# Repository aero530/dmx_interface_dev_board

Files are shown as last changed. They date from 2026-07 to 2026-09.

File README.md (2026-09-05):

# DMX Interface Dev Board v2 — Altium hardware

Production hardware for the **DMX Interface Rev 2**: a W6300-EVB-Pico2 (RP2350 +
W6300) carrier that takes Art-Net / sACN / wired DMX / USB in and drives eight
WS2812 strings, split across **two boards**. This repository holds the Altium
sources and generated manufacturing outputs. The firmware, design record, review
history and bring-up checklist live in `dmx_interface_firmware`.

| Board | Project | Size / stack | Job |
|---|---|---|---|
| **DMX Interface DB v2** (logic board) | `DMX Board/DMX Interface DB v2.PrjPcb` | 110 × 81.5 mm, 4-layer JLC04162H-7628, 1 oz outer / 0.5 oz inner, controlled impedance (USB 90 Ω, DMX 120 Ω) | Module, isolated DMX, FTDI USB-DMX port, UI, power tree, 8 × PTC-fused aux/data outputs |
| **LED Power Board** | `LED Power Board/LED Power Board.PrjPcb` | 85 × 90 mm, 4-layer, **2 oz outer** / 0.5 oz inner | Strip power only: screw-terminal input, 8 × 5 A MINI blade fuses, 470 µF per output, pluggable 5.08 mm outputs |

## Folder map

```
DMX Board/
  DMX Interface DB v2.PrjPcb      Altium project (7 sheets, harness-connected)
  Block Diagram.SchDoc            top sheet: module ↔ UI/LED/FTDI/DMX/Power, PSU options noted
  RP2350.SchDoc                   W6300-EVB-Pico2 socket (U1), RUN header, pin map
  WS2812.SchDoc                   SN74ACT245 level shift, 330 R series, 8 × PTSM 3-pin outputs with 3 A PTCs
  DMX.SchDoc                      isolated RS-485 front end (THVD1400, TLP2368 ×3, 1S7BE DC-DC), XLR-5 in/out
  FTDI.SchDoc                     FT232RNL self-powered USB-DMX port, USB-C, USBLC6, RESET# gate
  Power.SchDoc                    V_LED input (J26), F9 → L2/U6 → 5V_LOGIC → D2 → V_SYS → TLV75733, USB power paths
  UI.SchDoc                       TCA9555 (0x20), PCA9633 (0x62), M24C02 (0x56), TFT/button/PWM headers
  *.Harness                       harness definitions for the block diagram
  DMX Interface.PcbDoc            layout
  DMX Interface_Assy.PCBDwf, _FAB.PCBDwf   assembly / fabrication drawings
  DMX Interface.BomDoc            ActiveBOM (variant "Production")
  Job1.OutJob                     output job → "Project Outputs for DMX Interface DB v2/"
  Project Outputs for DMX Interface DB v2/
    BOM/  Gerber NC Drill/  OrCadPCB2Netlist/  PCB Print/  PCBDrawing/
    Report Board Stack/  Schematic Print/  Status Report.Txt
  review.md, DMX_Interface_Rev1_Design_Review.md   the Rev 1 (Nucleo + RP2040) review — identical copies, historical

LED Power Board/
  LED Power Board.PrjPcb, Sheet1.SchDoc, PCB1.PcbDoc
  Assembly Drawing.PCBDwf, Fabrication Drawing.PCBDwf, ActiveBOM.BomDoc
  Job1.OutJob (plus Assembly*.OutJob / Fabrication.OutJob)
  Project Outputs/                same structure as above

DMX_Interface_Multiboard_Project/   Altium multi-board project tying the two boards together (Assembly1.MbaDoc)
Panel Templates/                    only ECO logs — ignored
```

`.gitignore` excludes `__Previews/`, `History/` and every `Project Logs*/`
folder. The `Project Outputs` folders **are** tracked: they are what gets sent
to the fab and what the reviews were run against.

## Electrical summary

**Sources for `V_LED` on the logic board** (three, any one boots the logic):

1. **J26** (Molex Micro-Fit+ 206832-0801, 4 × V_LED + 4 × GND) from the PSU /
   LED Power Board — full power. Strip current stays on the power board; the
   logic board carries only its logic branch and eight 3 A aux/data feeds.
2. **FTDI USB-C (J2) with a plain 5 V brick** — low-power installs. U14
   TPS2553DBVR-1 USB power switch: current limit ≈ 1.45 A (R37 18k),
   reverse-voltage cut-off, EN from TCA9555 **P04** (R38 pull-down, off until
   firmware drives it high), FAULT to **P07** (R35 pull-up), soft start, then F2
   0ZCF0200FF2C 2 A PTC. **5 V build only** — F2 is DNP on 12/24 V builds.
3. **Module USB** — bench feed only: D3 B360A → F18 0.5 A PTC → V_LED.

The brick also boots the logic directly on any build through F1 (1.1 A PTC)
→ D4 → 5V_LOGIC. VBUS present-detect dividers (10k/20k) go to TCA9555 P05
(FTDI) and P06 (module). Trim the PSU to ≥ 5.2 V so it wins when both are
attached.

**Logic branch:** V_LED → F9 1.1 A PTC → L2 ferrite (5 V build) *or* U6
OKI-78SR-5/1.5 (12/24 V builds) → 5V_LOGIC (C17 47 µF SP-Cap) → D2 B340A →
V_SYS → module buck and U9 TLV75733 (3V3, enabled by module 3V3_OUT through
JP3/R26/R31 so the carrier rail never rises before the RP2350 IOVDD). L3 →
5V_LVL_SHIFT for U10.

**Build variants (one voltage per board, silk-marked):**

| | 5 V | 12 V | 24 V |
|---|---|---|---|
| L2 ferrite / U6 OKI | L2 fitted, U6 DNP | U6 fitted, L2 DNP | U6 fitted, L2 DNP |
| D1 TVS | SMDJ5.0A | SMDJ12A | SMDJ26A |
| F2 (brick path) | fitted | DNP | DNP |
| F10–F17 output PTCs | 0ZCF0300BF2C | 0ZCF0300BF2C | 0ZCF0150FF2C (≥ 30 V) |
| C2 | 50 V part on all builds | | |

**LED Power Board:** J3 (OSTYK, both positions V_LED) and J6 (both GND) →
eight Keystone 3544-2 MINI holders with 5 A 0297005.WXNV fuses → 470 µF per
output → Würth 691319510004 headers, mating plugs 691351500002. R1 10k bleed.
There is **no fuse, TVS or reverse protection on this board**: a 40–50 A
MIDI/ANL fuse in the PSU harness is required, and the only clamp is D1 on the
logic board through the J26 cable. Rated 8 × 5 A = 40 A through the board;
input band ≈ 15 mm of 2 oz copper, each output ≈ 8.5 mm.

**Isolation:** the DMX side (THVD1400, XLR shells excepted) sits on 3V3ISO /
GNDISO from PS1 (GAPTEC 1S7BE, 1 kV); plane split on both inner layers,
optocouplers straddle the gap; XLR shells bond to CHGND via PTH3 / R4 (0 Ω
fitted) / C1 (DNP).

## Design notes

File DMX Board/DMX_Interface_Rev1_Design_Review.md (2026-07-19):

# DMX Interface Rev 1 — Full Design Review

**Scope:** All 22 schematic sheets plus embedded netlist and BOM from `DMX_Interface_DB.pdf` (carrier board with NUCLEO-H563ZI + RP2040 Pico, isolated DMX front end, drive-select matrix, and SmartLED / Low-Power / High-Power output modules). Connectivity claims below were traced through the netlist embedded in the PDF, not just the drawings. Where the PDF extraction was ambiguous, the item is explicitly marked **VERIFY**.

**Verdict:** The architecture is sound and most of the board checks out — connector pin maps between carrier and modules are consistent, the isolation barrier is crossed correctly, I²C pull-up topology is clean, and the keying scheme prevents most mis-mating. However, this review found **several new hard errors on the RP2040 pin assignment and the drive-select matrix** that were not in your existing notes, plus two **absolute-maximum-rating hazards** (TLC59116 at 24 V, and 5 V into RP2040 GPIOs via the SmartLED level shifter). Details and a prioritized Rev 2 change list follow.

---

## 1. Critical — will not work as drawn

### 1.1 RP2040 DMX_I2C pins cannot map to a hardware I²C controller ⚠️ NEW

Netlist (sheet 10): `DMX_I2C.ALERT#` = GP4 (pin 6), `DMX_I2C.SDA` = **GP5** (pin 7), `DMX_I2C.SCL` = **GP6** (pin 9), annotated "I2C1".

On the RP2040, SDA is only available on even-numbered GPIOs and SCL on odd-numbered ones:

| GPIO | I²C capability |
|---|---|
| GP4 | I2C0 **SDA** |
| GP5 | I2C0 **SCL** |
| GP6 | I2C1 **SDA** |
| GP7 | I2C1 **SCL** |

As wired, SDA sits on an SCL-only pin and SCL on an SDA-only pin, and even relabeling in firmware leaves them on *different* controllers (GP5→I2C0, GP6→I2C1). **No hardware I²C configuration exists for this net assignment.** Since DMX_I2C is the STM32↔RP2040 inter-processor link and the RP2040 will most likely be the slave/peer, falling back to PIO I²C slave is possible but painful.

**Fix (Rev 2):** move `DMX_I2C.SDA` → GP6 and `DMX_I2C.SCL` → GP7 (valid I2C1 pair), and relocate `DMX_SPI.CS1` off GP7 (see 1.2 — GP9 is free and solves both problems). Alternatively SDA=GP4 / SCL=GP5 (I2C0) with ALERT# moved to GP6.

### 1.2 DMX_SPI.CS1 on GP7 is not a hardware SPI chip-select ⚠️ NEW

The populated solder-bridge configuration (SB2, SB5 ON; SB4, SB6 DNP) routes `DMX_SPI.MOSI` → GP8 (**SPI1 RX**) and `DMX_SPI.MISO` → GP11 (**SPI1 TX**), i.e. the RP2040 is wired as the **SPI slave** with the STM32 (SPI6) as master. GP10 = SPI1 SCK is correct. But `DMX_SPI.CS1` lands on **GP7**, which is SPI0 TX — not a CSn pin. The PL022 in slave mode requires CS on a hardware CSn pin (SPI1 CSn = GP9 or GP13). GP13 is taken by `RP2040_SCL`; **GP9 (module pin 12) is currently unconnected** and is the natural fix.

Until fixed, hardware SPI slave mode cannot frame transactions; you'd need a PIO SPI slave.

### 1.3 Drive-select matrix crosses RP_LED3.Data and RP_LED4.Data ⚠️ NEW

On the Drive Select sheet, the RP2040-side (pin 3) nets of the LED data jumpers are crossed relative to the clock jumpers:

| Jumper | Module net (pin 2) | STM32 side (pin 1) | RP2040 side (pin 3) |
|---|---|---|---|
| JP17 | LED3_CLK | STM32_LED3.Clock | RP_LED3.Clock ✓ |
| JP18 | LED3_DAT | STM32_LED3.Data | **RP_LED4.Data ✗** |
| JP19 | LED4_CLK | STM32_LED4.Clock | RP_LED4.Clock ✓ |
| JP20 | LED4_DAT | STM32_LED4.Data | **RP_LED3.Data ✗** |

JP12/13/15/16 (channels 1–2) are consistent. With the RP2040 selected as LED driver, channel 3's clock pairs with channel 4's data and vice versa. The RP2040 can absorb this in firmware (PIO pin mapping is free), but it will silently corrupt any code that assumes the net names — and the same crossover is reflected on the block-diagram sheet, so it propagates into documentation. Swap the pin-3 nets of JP18/JP20.

Note also: with the default build, the RP2040 cannot drive channel 4 at all — `RP_LED4.Clock`/`RP_LED4.Data` reach GP10/GP11 only through **DNP** bridges SB8/SB3, which are shared with the DMX_SPI pins. That's a deliberate either/or, but worth stating in the docs.

### 1.4 SmartLED DIR net anomalies — **VERIFY in Altium** ⚠️ NEW

The extracted netlist shows the SN74ACT245 `DIR` node (U10 pin 1, JP21 pin 2) also containing **J18 pin 3 and J20 pin 3**, and possibly **U13 pin 1 (EEPROM E0) plus JP24 pin 2**. Two problems if real:

1. J10/J13 carry V_LED on pins 1 *and* 3, but J18/J20 carry V_LED only on pin 1 — pin 3 lands on the DIR logic node. A strip plugged into J18/J20 expecting power on pin 3 would fight or glitch the transceiver direction. There's no evident reason for power connectors to carry DIR.
2. If E0/JP24 truly share the node: JP21 selects 5V_LVL_SHIFT/GND and JP24 selects 3V3/GND on the *same net*. Both at default (1-2) would short **5 V to GND**, and any high state puts 5 V on the M24C02's E0 pin (abs max VCC + 1 V = 4.3 V). The EEPROM address table ("default 0x56", E0=0) also stops being independently settable.

PDF net extraction can merge adjacent nets, so treat this as a must-verify rather than a confirmed fault — but the J18/J20 pin-3 assignment is suspicious even in the most charitable reading.

### 1.5 3V3 → RP_VSYS ideal diode (U14) non-functional — known

Confirmed: AP74700 requires ~4 V minimum anode voltage, so the 3V3 ORing leg into RP_VSYS is dead, as your sheet-1 note says. TPS2116 / LM66100 / Schottky-OR are the right class of fix. (RP_VSYS is happy from 1.8 V, so even a Schottky's drop from 3.3 V is fine.)

---

## 2. Damage and ratings risks

### 2.1 TLC59116 outputs are 17 V absolute max — 24 V supplies will kill the LP module ⚠️ NEW

The carrier explicitly supports 24 V Meanwell bricks (sheet 1 lists LSP-160-24T / UHP-200-24), and V_LED is bussed unchanged to the Low-Power module's J37 common-anode connectors. The TLC59116's OUTx pins are rated **17 V absolute maximum** in the off state; the sheet note itself says "(12V 3W)". Nothing electrically or mechanically prevents installing the LP module with a 24 V supply — the off-state sink pins will see 24 V and exceed abs max. At minimum, silkscreen + docs must restrict the LP module to ≤12 V (≤15 V with margin); a better Rev 2 fix is a module-local regulator/clamp or a keying/interlock convention per supply voltage.

### 2.2 Reverse direction on U10 drives 5 V into non-5V-tolerant RP2040 pins ⚠️ NEW

The SN74ACT245 runs at `5V_LVL_SHIFT`. JP21 in the DIR-low position (B→A, "read data back from strips") turns the A-side pins into ~5 V CMOS outputs driving straight through the module connector and drive-select into the MCU pins with no series resistance. STM32H5 FT pins tolerate this; **RP2040 GPIOs do not (max VDDIO + 0.3 V ≈ 3.6 V)**. If the reverse direction is ever a supported mode, add series resistors and/or clamp, or drop U10's VCC to 3.3 V for that use case. If it's not a supported mode, remove the JP21 GND option or document it as forbidden. Also note DIR is common to all 8 bits, and a direction flip while the MCU still drives its outputs creates transceiver-vs-MCU contention.

### 2.3 TVS and reverse-polarity protection on V_LED — known, plus one addition

SMAJ26A (D1/D2/D7) at 26 V standoff over a 24 V rail leaves ~2 V margin; supply turn-on overshoot can bias the TVS into leakage/heating. SMAJ28A/30A recommended. Additional point: the TVS conducts hard on reverse polarity but there is **no fuse or series element on any V_LED input** (J8/J30/J32) — a reversed 200 W brick will destroy the TVS and then the board. A polyfuse or input FET per module power connector is cheap insurance even on a dev board.

### 2.4 TLC59116 Rext floor — known, confirmed

R57 = 120 Ω fixed + VR1 (3306P, spec'd 30 Ω–1 kΩ but wiper can approach 0 Ω). At wiper ≈ 0, Rext → 120 Ω → ~156 mA/channel, above the 120 mA device limit. Raise R57 to ≥160 Ω so the minimum is safe regardless of trimmer position.

### 2.5 TLC59116 thermal budget — worth a calculation ⚠️ NEW

As a linear sink, per-channel dissipation is (V_LED − V_string) × I_OUT. At 12 V with short strings and ~117 mA, several channels active can put multiple watts into one TSSOP28. Run the worst-case sum for your intended loads; you may want to mandate series resistors or higher-Vf strings to move dissipation off-chip.

### 2.6 Jumper/e-fuse configuration hazards ⚠️ NEW

- **JP14 in the 5 V position with a 12/24 V supply** puts V_LED directly into U9 (LS0504, 6 V abs max) and onto `5V_LVL_SHIFT` → U10 and the strips. One wrong solder bridge = dead module. Consider an auto-select (comparator or wide-Vin buck) instead of a bridge, or at least prominent silkscreen.
- F1/F2 PTCs are 6 V parts. They never see >5 V while the AP74700s block correctly, but a shorted Q1/Q2 exposes them to 24 V, beyond their interrupt rating. Acceptable dev-board risk; noting for awareness.
- JP1/JP22/JP23 populated *with* an external brick present is actually safe (the ideal diodes block reverse into USB) — the silkscreen warnings are belt-and-braces, which is fine.

### 2.7 Multiple modules, multiple power inputs ⚠️ NEW

Each module carries its own brick input (J8, J30, J32) and all common onto the same V_LED through the carrier. Plugging *different* bricks into two installed modules (e.g., 5 V and 24 V) back-drives one supply from the other. Document "one brick per system," or add ORing/blocking per module input in a future rev.

---

## 3. Functional and performance findings

### 3.1 RP2040 DMX UART pins require PIO ⚠️ NEW (likely intentional — confirm)

`DMX.RX` = GP0, `DMX.EN` = GP2, `DMX.TX` = GP3. GP0 is UART0 **TX**-capable (not RX), and GP3 is UART0 CTS (not TX) — so the hardware UART cannot service DMX on these pins in either direction. Since DMX break/MAB timing is normally done with PIO on the RP2040 anyway (e.g., pico-dmx), this is fine *if intended* — but if you ever wanted the hardware UART as a fallback, RX belongs on GP1/GP13/GP17 and TX on GP0/GP4/GP8/GP12/GP16. Worth a schematic note either way.

### 3.2 Opto LED drive margin (RX path) — known, quantified

U8 input: (3.3 V − ~1.4 V Vf − VOL) / 470 Ω ≈ **3.8 mA**. Check this against the TLP2368 threshold input current across temperature; the recommended operating IF for these photo-IC couplers is typically ≥6.5 mA. Dropping R13 to ~270 Ω would put you comfortably in the recommended range (THVD1400 RO can sink it).

### 3.3 R-78K3.3-1.0 minimum input — known

With a 5 V brick, V_LED minus L2 DCR and ripple sits right at the R-78K3.3's ~4.75 V minimum. Fine at 12/24 V. If 5 V operation matters, consider a lower-Vin-min module or LDO bypass path.

### 3.4 STM32 hardware PWM availability for the HP module — refined ⚠️ NEW DETAIL

HP module PWM sources (via J17_H): PWM1 = LED1_DAT or LED1_CLK (JP26, default CLK), PWM2 = LED2_DAT, PWM3 = LED3_DAT, PWM4 = LED4_DAT. Mapping to STM32 pins:

| Signal | STM32 pin | SPI AF | Timer channel |
|---|---|---|---|
| LED1_CLK | PA5 | SPI1_SCK | **TIM2_CH1 ✓** (JP26 default — good) |
| LED1_DAT | PD7 | SPI1_MOSI | none (verify) |
| LED2_DAT | PC3 | SPI2_MOSI | none (verify) |
| LED3_DAT | PB2 | SPI3_MOSI | none (verify) |
| LED4_DAT | PE14 | SPI4_MOSI | **TIM1_CH4 ✓** |
| LED2_CLK | PB10 | SPI2_SCK | TIM2_CH3 ✓ |
| LED4_CLK | PE12 | SPI4_SCK | TIM1_CH3N ✓ |

So on the STM32, only PWM1 (via JP26→CLK) and PWM4 get hardware PWM; PWM2/PWM3 fall back to software toggling. If HP dimming from the STM32 matters, add JP26-style CLK/DAT select jumpers to PWM2 and PWM4 as well (LED2_CLK = PB10/TIM2_CH3 and LED4_CLK = PE12/TIM1_CH3N are usable), and verify the "none" entries against the H563 datasheet AF table. RP2040 side is a non-issue (PWM/PIO on any pin).

### 3.5 Series resistors on DAT only

R17–R20 (330 Ω, provisional) are in the data lines only; clocks go straight from U10 to the LED connectors. For APA102-class strips on any cable length, matching series R on CLK helps edges/ringing just as much. Add provisional footprints on the four CLK lines.

### 3.6 Dual 3V3 sources / Nucleo contention — known, with one addition

The carrier 3V3 (U11) ties to the Nucleo's 3V3 pin **through the unannotated `R?` 0 Ω** (see §6) — so the contention point is at least depopulatable. Document the required Nucleo solder-bridge configuration for external-3V3 powering, and give R? a real designator so it shows up in assembly docs.

### 3.7 No fusing on LED power outputs ⚠️ NEW

J10/J13/J18/J20, LED1–4, J37_PWMx, and J33 all distribute up to a 200 W brick with no per-output protection. A shorted strip cable turns the wiring into the fuse. Recommend polyfuses or fuse footprints per output group in Rev 2.

### 3.8 Module EEPROM addressing — known

U13/U15/U21 all default to 0x56 (E1/E2 strapped high via 0 Ω, E0 low). Fine with one module per connector position, but strapping each module *type* to a distinct 0x5x enables type detection by address probe. TLC59116 at 0x60 (+ all-call/sub-call/SWRST in the 0x68–0x70 region) doesn't collide with 0x56 — bus is clean.

---

## 4. Connector and pinout verification

Traced pin-for-pin through the netlist:

| Interface | Result |
|---|---|
| J7 (carrier, power) ↔ J9_S/L/H (modules) | ✓ Match: 1,2 = V_LED; 3,4 = GND; 5,6 = 3V3; 7,8 = GND |
| J11 (carrier, control) ↔ J12_S/L/H | ✓ Match: 1=ALERT#, 2=SCL, 3=RESET#, 4=SDA, 5=CS1, 6=SCK, 7=CS2, 8=MISO, 9=CS3, 10=MOSI |
| J16 (carrier, LED) ↔ J17_S/L/H | ✓ Match: odd pins = DATn, even pins = CLKn, n = 1..4 |
| HP PWM mapping | ✓ Consistent: J17_H pins 3/5/7 (= LED2/3/4_DAT) → PWM2/3/4; no odd/even swap found (resolves the earlier suspicion) |
| Micro-Fit+ keying (A-key LED1–4 vs D-key J10/13/18/20) | ✓ Prevents signal/power mis-mating |
| DMX XLR genders | ✓ J5 male = input, J15 female = output — matches DMX512 convention |
| SmartLED channel numbering | Confirmed mechanism of your silkscreen note: U10 A1/A2 carry **LED4**_DAT/CLK → B1/B2 → connector "LED1", etc. Pairing (DAT+CLK) is preserved per connector, so it's purely a labeling reversal — connector LEDn carries channel (5−n). Fix silkscreen or swap A-side order in Rev 2. |
| DMX pass-through | ✓ Pins 2/3 (data) and 4/5 (aux pair) bused straight between J5 and J15; JP28 + R15/R16 = switchable 120 Ω termination |
| J5/J15 rendered with "X" | **VERIFY** — confirm placeholder graphic vs. unintended DNP (carried over from previous notes) |
| Board-to-board mating orientation | **VERIFY mechanically** — dual-row RA female (carrier) to dual-row RA male (module) at facing edges should keep pin 1↔pin 1, but row-mirroring is the classic failure mode for this construction; check in 3D/first article |

---

## 5. Items verified OK

- **Isolation barrier crossing:** U3/U7 (TX/EN) LED-side on logic 3V3, output-side on 3V3ISO; U8 (RX) reversed — all correct. PS1 (1S7BE, 1 W) budget ≈ 50–60 mA worst case on 3V3ISO — ample.
- **RS-485 fail-safe bias:** 680 Ω / 120 Ω / 680 Ω gives ≈ 270 mV differential idle — above the 200 mV threshold, plus THVD1400's internal fail-safe. Good.
- **DE//RE tied and driven together** via U7 — correct for a DMX transmitter/transceiver; no local echo, which is fine.
- **CHGND scheme:** XLR shells → CHGND → R1 (0 Ω) → logic GND; XLR pin 1 → GNDISO. Reasonable; keep R1 as the tuning point.
- **I²C pull-up topology:** exactly one 2.2 kΩ set per physical bus segment on each of DMX_I2C, OUTPUT_I2C (STM32 side) / RP2040 I²C (RP side), DISPLAY_I2C — no double termination through the drive-select. 2.2 k at 3.3 V = 1.5 mA sink, fine for Fm.
- **STM32 I²C assignments spot-checked:** I2C1 = PB8/PB9 (DMX) ✓; I2C2 = PF1/PF0 (display) ✓; I2C4_SDA = PF15 and I2C4_SMBA = PF13 (output bus) ✓ — SCL should therefore be PF14; the PDF extraction was ambiguous on that one pin, quick check recommended.
- **RP2040 OUTPUT-side I²C:** GP12/GP13 = valid I2C0 SDA/SCL ✓ (which is what makes the DMX_I2C error in §1.1 stand out).
- **Drive-select SPI/I²C/CLK jumpers** (JP2–JP17, JP19, JP29–JP34): all pin-1/pin-3 source nets consistent; only JP18/JP20 are crossed.
- **RP2040 reset:** STM32 PG1 + J14 jumper onto RUN (internal pull-up on Pico) ✓. RP2040 SWD not broken out on the carrier, but the Pico's own debug pads remain accessible.
- **EEPROM write protection:** WC pulled high (10 k) on all three modules, ground-bridge to enable writes ✓.
- **TLC59116 address straps:** JP35–38 default to GND → 0x60, matching the note ✓.
- **HP driver (TPS922051) design:** 65 V part, PMEG100T030 (100 V/3 A) catch diode, VIN-referenced LED string with 0.2 Ω sense via 100 Ω/1 nF filter — matches the TI reference topology; component ratings fine at 24 V.
- **Bulk/output caps:** 470 µF/50 V electrolytics, 50 V ceramics on V_LED nodes — rated for the 24 V option ✓ (C12 tantalum is on 3V3ISO at 10 V rating — 3.3/10 derating fine).
- **Q1/Q2/Q3 (55–60 V FETs) and AP74700 (40 V max)** — fine against 24 V exposure.

---

## 6. Documentation / librarian issues

1. `R?` / value `0R?` on sheet 3 — this is the carrier-3V3-to-Nucleo-3V3 tie and it appears as "R?" in the BOM too. Re-run annotation before release.
2. Drive Select sheet has a completely blank title block (no title/number/sheet index).
3. Every sheet says "Sheet x of 22" but the set runs to 24 pages including the layout/BOM pages — reconcile.
4. Silkscreen: LED DAT/CLK flipped; DAT[1-4]/CLK[1-4] should read [4..1] (or fix electrically per §4).
5. Block diagram reflects the JP18/JP20 crossover (§1.3) — fix both together.
6. SmartLED layer to-do noted on the layout page ("add power plane to signal layer").
7. Sheet-1 red note boxes should be resolved/cleared as items close.

---

## 7. BOM review

- **GCM1885C1H101JA16D (C96_HPx, 100 pF) is marked "Not Recommended for New Design"** in your own BOM export — pick a replacement now (e.g., GRM1885C1H101JA01 or GCM equivalent in production status).
- F1 (0ZCG, 3 A) and F2 (0ZCJ, 1 A) are 6 V PTCs — see §2.6.
- VR1 3306P-1-102: single-turn trimmer setting a safety-relevant current limit — a fixed resistor + optional parallel trim, or a multi-turn part, is more robust (pairs with §2.4).
- J11 listed as Würth 613010243121 — confirm this is actually the *socket* variant; that part family number reads like a pin header. All other female/male pairings (Sullins/Adam Tech) look consistent.
- 33 solder-bridge jumpers all default 1-2: confirm that default is correct for **every** instance (it is for the drive-select = STM32 and TLC address = 0x60; verify JP21/JP24/JP26 intents against §1.4 and §3.4).

---

## 8. Prioritized Rev 2 change list

| # | Priority | Change |
|---|---|---|
| 1 | Blocker | Re-pin RP2040 DMX_I2C: SDA→GP6, SCL→GP7 (I2C1) |
| 2 | Blocker | Move DMX_SPI.CS1 GP7→GP9 (SPI1 CSn; GP9 currently free) |
| 3 | Blocker | Swap JP18/JP20 pin-3 nets (RP_LED3.Data ↔ RP_LED4.Data) |
| 4 | Blocker | Resolve SmartLED DIR net: remove J18/J20 pin 3 from DIR; confirm E0/JP24 is a separate net (§1.4) |
| 5 | High | Replace U14 AP74700 with low-voltage ORing (TPS2116/LM66100/Schottky) for 3V3→RP_VSYS |
| 6 | High | Enforce/inhibit LP module above ~15 V V_LED (TLC59116 17 V abs max) |
| 7 | High | Protect RP2040 from 5 V in U10 B→A mode (series R / clamp / forbid mode) |
| 8 | High | Raise R57 so Rext ≥ ~160 Ω at trimmer minimum |
| 9 | Medium | TVS → SMAJ28A/30A; add fusing on V_LED inputs and LED power outputs |
| 10 | Medium | Reduce R13 to ~270 Ω for opto RX margin; verify TLP2368 IF threshold |
| 11 | Medium | Add CLK/DAT select jumpers on HP PWM2/PWM4 for hardware timer channels; verify PD7/PC3/PB2 timer AFs |
| 12 | Medium | Series-R footprints on the four CLK lines to LED connectors |
| 13 | Medium | Distinct EEPROM addresses per module type |
| 14 | Low | Fix silkscreen numbering, annotation (R?), Drive Select title block, sheet counts; replace NRND C96 part; document one-brick rule and Nucleo power-bridge config |

---

*Method note: pin/net claims were cross-checked against the netlist embedded in the PDF (e.g., `PIU507 → DMX_I2C.SDA`, `PIJP1803 → RP_LED4.Data`). RP2040 GPIO function mapping is from the RP2040 datasheet Bank 0 function table. STM32H563 alternate-function claims marked "verify" should be checked against the datasheet AF tables before committing the Rev 2 netlist.*

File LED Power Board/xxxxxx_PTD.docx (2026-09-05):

# xxxxxx_PTD

Programming and Test instructions

# Revision History

Revision | Date | By | Changelog
A | 2024-11-27 | Phil Spindler | Initial Release

# Summary

## Document Parameters

The following parameters are used in other parts of this document and are likely to change over the course of the product life (e.g. when a firmware update is issued).

Parameter | Value
AssyPartNumber | 123456

# Program and Configure

Supporting Information
Purpose | Program board components with necessary firmware for correct device operation, verify firmware.
Prerequisites | Fully assembled circuit card assembly
Equipment | - STLINK v2 - Power source for powering board (5-9V)
Relevant Pinouts | [J3] Programming/Debug Through-Hole Test Points Pin Signal STLINK Pin 1 3.3V 1 2 SWCLK 9 3 SWDIO 7 4 #RESET 15 5 GND 2 6 UART RX - 7 UART TX - 8 #RUN/BOOT - 9 DEBUG MODE - [J4] Power Through-Hole Test Points Pin Signal 1 5-9VDC 2 GND

Process
Note | | n/a
1 | Setup | Connect PCBA to programming and power interface described in “Pinouts” (either via connectors or test pads) using STLINK v2. Note pins in J3 and J4 are through-hole test pads with a pin spacing of 2.54mm and a hole size of 1mm.
2 | Power | Apply power to the device via J4
3 | Program | Program device using the following command. Program_the_thing.exe -i <FIRMWARE FILE PENDING> -s {AssyPartNumber}
4 | Check Result | Programming utility must report success with no errors.

# Verify

Supporting Information
Purpose | Verify board functions correctly
Prerequisites | Fully Assembled, registered, programmed & configured circuit card assembly.
Equipment | - Power source for DUT power (5V -> 9V) - 3.3V UART interface for J3 UART pins
Relevant Pinouts | [J3] Programming/Debug Through-Hole Test Points Pin Signal Host UART Interface 1 3.3V - 2 SWCLK - 3 SWDIO - 4 #RESET - 5 GND GND 6 UART RX RX 7 UART TX TX 8 #RUN/BOOT - 9 DEBUG MODE - [J4] Power Through-Hole Test Points Pin Signal 1 5-9VDC 2 GND
UART Configuration | Baud Rate: 921600 Data Bits: 8 Parity Bits: None Stop Bits: 1

Process
1 | Setup | Connect board to programming and power interface described in “Pinouts” (either via connectors or test pads) using STLINK v2. Note pins in J3 and J4 are through-hole test pads with a pin spacing of 2.54mm and a hole size of 1mm.
2 | Power | Apply power to the device via J4
3 | Verify | On boot, the device will issue information over the UART interface.

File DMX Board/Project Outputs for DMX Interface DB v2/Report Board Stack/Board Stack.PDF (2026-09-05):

# Board Stack Report

Stack Up | Layer Stack
Layer | Board Layer Stack | Name | Material | Thickness | Constant

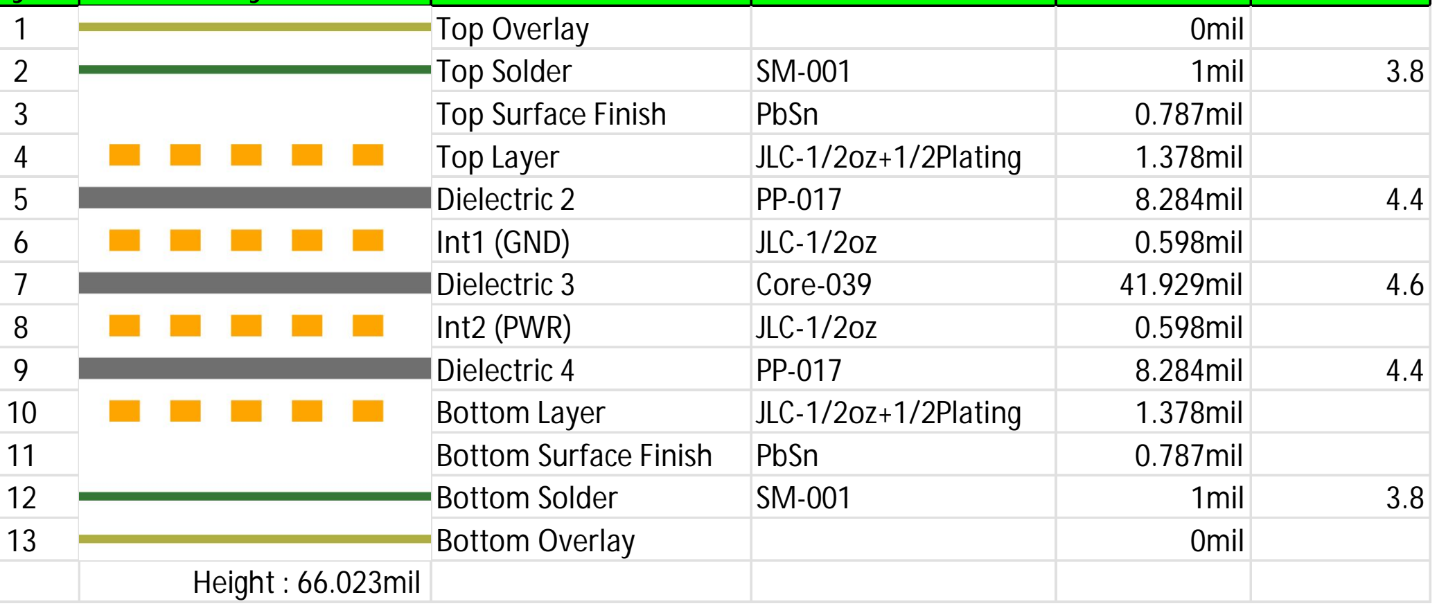
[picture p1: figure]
Top Overlay; 0mil; Top Solder; 1mil; Top Surface Finish; PbSn; 0.787mil; Top Layer; JLC-1/2oz+1/2Plating; 1.378mil; Dielectric 2; 8.284mil; Int1 (GND); JLC-1/2oz; 0.598mil; Dielectric 3; Core-039; 41.929mil; Int2 (PWR); Dielectric 4; Bottom Layer; Bottom Surface Finish; Bottom Solder; Bottom Overlay; Height : 66.023mil

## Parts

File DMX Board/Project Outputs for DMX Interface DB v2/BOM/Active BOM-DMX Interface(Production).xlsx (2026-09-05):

JLCPN | Name | Description | Designator | Footprint | LibRef | Quantity | Manufacturer 1 | Manufacturer Part Number 1 | Supplier 1 | Supplier Part Number 1
C440198 | GRM21BR61H106KE43L | Ceramic Capacitor, Multilayer, Ceramic, 10uF, 50V, 10%, X6S, 0805 | C2 | CAPC2012X14N_0805_MED | CMP-001-00169-2 | 1
 | REH1020471M050K | CAP ALUM 470UF 20% 50V RADIAL TH | C3, C6, C7, C11, C18, C24, C26, C28 | CAP_POL_DIAM10_H22_SPACING5 | CMP-001-00166-2 | 8 | KYOCERA AVX | REH1020471M050K | Mouser | 581-REH1020471M050K
C59782 | C1608X7R1C105K080AC | Ceramic Capacitor, Multilayer, Ceramic, 16V, 10% +Tol, 10% -Tol, X7R, 15% TC, 1uF, Surface Mount, 0603 | C4, C39 | CAPC1608X10N_0603_MED | CMP-001-00121-2 | 2 | TDK | C1608X7R1C105K080AC | Newark | C1608X7R1C105K080AC
C113803 | CC0603KRX7R0BB104 | Ceramic Capacitor, Multilayer, Ceramic, 100V, 10% +Tol, 10% -Tol, X7R, 15% TC, 0.1uF, Surface Mount, 0603 | C5, C8, C9, C10, C13, C14, C16, C23, C29, C30, C32, C33, C34, C36, C42, C43, C44 | CAPC1608X10N_0603_MED | CMP-001-00102-4 | 17 | Yageo Group | CC0603KRX7R0BB104 | Arrow Electronics | CC0603KRX7R0BB104
C55530 | TPSB226K010R0500 | Tantalum Capacitor, Polarized, Tantalum (dry/solid), 10V, 10% +Tol, 10% -Tol, 22uF, Surface Mount, 1210 | C12 | CAPCP3528X21N_1210_1411_MED | CMP-001-00100-5 | 1 | KYOCERA AVX | TPSB226K010R0500 | Arrow Electronics | TPSB226K010R0500
C125847 | CGA4J3X7R1H225K125AE | Ceramic Capacitor, Multilayer, Ceramic, 2.2uF, 50V, 10%, X6S, 0805 | C15, C22 | CAPC2012X14N_0805_MED | CMP-001-00170-2 | 2 | TDK | CGA4J3X7R1H225K125AE | Newark | CGA4J3X7R1H225K125AE
 | EEF-CX1C470R | Polymer Aluminum Electrolytic Capacitor, 47 µF, -55 to 105 ¡C | C17 | FP-SP-Cap-X-MFG | CMP-001-00179-1 | 1
C162413 | GRM21BC81C106KA73L | Ceramic Capacitor, Multilayer, Ceramic, 10uF, 16V, 10%, X6S, 0805 | C31, C40, C41 | CAPC2012X14N_0805_MED | CMP-001-00084-4 | 3 | Murata | GRM21BC81C106KA73L | DigiKey | 490-5519-6-ND
 | GRM21BC81C226ME44L | Ceramic Capacitor, Multilayer, Ceramic, 22uF, 16V, 20%, X6S, 0805 | C38, C45 | CAPC2012X14N_0805_MED | CMP-001-00095-1 | 2
 | SMDJ5.0A | SMDJ Series 6.5 W 7 V Uni-Directional Surface Mount TVS Diode - SMC | D1 | SMDJ_DO-214AB | CMP-004-00055-2 | 1 | Littelfuse | SMDJ5.0A | Arrow Electronics | SMDJ5.0A
 | B340A-13-F | Rectifier Diode, Schottky, 1 Phase, 1 Element, 3A, 40V V(RRM), Silicon | D2 | DO-214AC_SMA | CMP-004-00034-2 | 1 | Diodes Inc. | B340A-13-F | Newark | B340A-13-F
 | B360A-13-F | Rectifier Diode, Schottky, 1 Phase, 1 Element, 3A, 60V V(RRM), Silicon, DO-214AC | D3, D4 | FP-SMA-MFG | CMP-004-00054-1 | 2
 | 1812L110/33MR | PTC Resettable Fuse 1.1A(hold) 1.95A(trip) 33VDC 20A 0.8W 0.5s 0.06Ohm SMD Solder Pad 1812 T/R | F1, F9 | FUSE4532X1.55N_1812MED | CMP-005-00022-1 | 2 | Littelfuse | 1812L110/33MR | Arrow Electronics | 1812L110/33MR
 | 0ZCF0200FF2C | SMD Resettable Fuse, PPTC, 2920 [7351 Metric], 0ZCF, 16 VDC, 2 A, 4 A, 4.5 s | F2 | RESC7451X90M_2920 | CMP-005-00026-1 | 1
 | 0ZCF0300BF2C | Polymeric PTC Resettable Fuse 24V 3 A Ih Surface Mount 2920 (7351 Metric), Conca | F10, F11, F12, F13, F14, F15, F16, F17 | 0ZCF0300BF2C-Footprint-1 | CMP-005-00023-1 | 8
C151162 | 1206L050/15YR | PTC Resettable Fuse 0.5A(hold) 1A(trip) 15VDC 100A 0.6W 0.1s 0.15Ohm SMD Solder Pad 1206 T/R | F18 | FP-1206L-MFG | CMP-005-00020-2 | 1 | Littelfuse | 1206L050/15YR | RS (Formerly Allied Electronics) | 1206L050/15YR
 | 1778638 | Terminal Block, Header, R/A, 3Way, Th; | J1, J3, J13, J16, J20, J21, J24, J25 | 1778638-Footprint-1 | CMP-002-00251-3 | 8
C165948 | TYPE-C-31-M-12 | 20V USB C 2.0 16P Female header | J2 | Type-C-31-M-12 | CMP-002-00236-8 | 1 | Global Connector Technology | USB4105-GF-A | Mouser | 640-USB4105-GF-A
 | Header 8x1 0.1" | Conn Header Vert 8POS 2.54MM | J4 | HEADER 8x1 0.1" | CMP-002-00240-1 | 1 | Adam Tech | PH1-08-UA | Arrow Electronics | PH1-08-UA
 | IO-XLR5-M-BH | B Series, 5 Pin XLR, Male, Horizontal Pcb Mount With Separate Ground Pin | J5 | IO-XLR5-M-BH-Footprint-1 | CMP-002-00191-7 | 1 | Io Audio Technologies | IO-XLR5-M-EH | Jameco (USA) | 2388023
 | Header 5x1 0.1" | Conn Header Vert 5POS 2.54MM | J6, J8 | HEADER 5x1 0.1" | CMP-002-00239-1 | 2 | Adam Tech | PH1-05-UA | Arrow Electronics | PH1-05-UA
 | Header 6x1 0.1" | Conn Header Vert 6POS 2.54MM | J7 | Copy of HEADER 7x1 0.1" | CMP-002-00250-1 | 1
 | Header 2x1 0.1" | Conn Header Vert 2POS 2.54MM | J9, J14 | FP-M20-9990245-MFG | CMP-002-00082-2 | 2 | Adam Tech | PH1-02-UA | RS (Formerly Allied Electronics) | PH1-02-UA
 | 1778845 | Terminal Block Connector; Plug; Mini; Spring Cage; 3; 2.5 mm; 26-20 AWG; 5 A; 150 V | J10, J11, J12, J17, J18, J19, J22, J23 | 1778845-Footprint-1 | CMP-002-00252-2 | 8
 | IO-XLR5-F-BH | B-Series 5-Pin XLR Female Horizontal PCB Mount with Separate Ground-Pin Metal Face Plate | J15 | IO-XLR5-F-BH-Footprint-1 | CMP-002-00192-4 | 1 | Io Audio Technologies | IO-XLR5-F-EH | Mouser | 670-IO-XLR5-F-EH
 | 206832-0801 | Micro-Fit+, Vertical Header, 8 pin | J26 | 206832-0801-Footprint-1 | CMP-002-00208-6 | 1
 | Jumper 3 x 1 Bridge 1-2 Solder Bridge | 0603 Solder Bridge Jumper Surface Mount | JP1, JP2, JP3, JP4, JP5 | Jumper 3 Solder Bridge 1-2 0603 | CMP-009-00341-2 | 5
 | SRR6038-180Y | General Purpose Inductor, 18uH, 30%, 1 Element, Ferrite-Core, SMD, 2727 | L1 | IND_SRR6038-180Y | CMP-006-00028-1 | 1 | Bourns | SRR6038-180Y | Mouser | 652-SRR6038-180Y
 | MPZ2012S601AT000 | Ferrite Beads Multi-Layer Power 600Ohm 25% 100MHz 2A 0.1Ohm DCR 0805 T/R | L2, L3 | FP-MPZ2012-MFG | CMP-006-00035-1 | 2 | TDK | MPZ2012S601AT000 | DigiKey | 445-MPZ2012S601AT000DKR-ND
 | 1S7BE_0303S3U | ISOLATED MODULE DC DC CONVERTERS | PS1 | CONV_1S7BE_0303S3U | CMP-112-000000-3 | 1 | GAPTEC Electronic GmbH & Co. KG | 1S7BE_0303S3U | DigiKey | 3182-1S7BE_0303S3U-ND
 | 2N7002KW | Small Signal Field-Effect Transistor, 0.31A I(D), 60V, 1-Element, N-Channel, Silicon, Metal-oxide Semiconductor FET | Q1 | ONSEMI_SOT65P210X110-3N | CMP-013-00041-2 | 1 | onsemi | 2N7002KW | Arrow Electronics | 2N7002KW
C22962 | RC0603FR-07220RL | Fixed Resistor, Metal Glaze/thick Film, 0.1W, 220ohm, 75V, 1% +/-Tol, 100ppm/Cel, Surface Mount, 0603 | R1, R9, R13 | RESC1608X06N_0603_MED | CMP-009-00202-2 | 3 | Yageo Group | RC0603FR-07220RL | Arrow Electronics | RC0603FR-07220RL
C25803 | RC0603DR-07100KL | Fixed Resistor, Metal Glaze/thick Film, 0.1W, 100000ohm, 75V, 0.5% +/-Tol, 100ppm/Cel, Surface Mount, 0603 | R2, R31, R35, R38 | RESC1608X06N_0603_MED | CMP-009-00328-3 | 4 | Yageo Group | RC0603DR-07100KL | Arrow Electronics | RC0603DR-07100KL
C22935 | RC0603FR-071ML | Fixed Resistor, Metal Glaze/thick Film, 0.1W, 1Mohm, | R3 | RESC1608X06N_0603_MED | CMP-009-00342-2 | 1 | Yageo Group | RC0603FR-071ML | Mouser | 603-RC0603FR-071ML
C21189 | RC0603FR-070RL | RC Series 0603 0.1 W 0 Ohm Jumper Surface Mount Thick Film Chip Resistor | R4, R5, R29, R30, R32, R33, R34 | RESC1608X06N_0603_MED | CMP-009-00204-6 | 7 | Yageo Group | RC0603JR-070RL | Mouser | 603-RC0603JR-070RL
C23138 | RC0603FR-07330RL | Fixed Resistor, Metal Glaze/thick Film, 0.1W, 330ohm, 75V, 1% +/-Tol, 100ppm/Cel, Surface Mount, 0603 | R6, R12, R15, R16, R17, R18, R19, R20, R21 | RESC1608X06N_0603_MED | CMP-009-00302-3 | 9 | Yageo Group | RC0603FR-07330RL | Mouser | 603-RC0603FR-07330RL
C114669 | RC0603FR-07470RL | Fixed Resistor, Metal Glaze/thick Film, 0.1W, 470ohm, 75V, 1% +/-Tol, 100ppm/Cel, Surface Mount, 0603 | R7, R8 | RESC1608X06N_0603_MED | CMP-009-00300-2 | 2 | Yageo Group | RC0603FR-07470RL | Mouser | 603-RC0603FR-07470RL
C112310 | RC0603FR-07680RL | Fixed Resistor, Metal Glaze/thick Film, 0.1W, 680ohm, 75V, 1% +/-Tol, 100ppm/Cel, Surface Mount, 0603 | R10, R11 | RESC1608X06N_0603_MED | CMP-009-00301-2 | 2 | Yageo Group | RC0603FR-07680RL | Arrow Electronics | RC0603FR-07680RL
C114662 | RC0603FR-072K2L | Fixed Resistor, Metal Glaze/thick Film, 0.1W, 2200ohm, 75V, 1% +/-Tol, 100ppm/Cel, Surface Mount, 0603 | R14, R27, R28 | RESC1608X06N_0603_MED | CMP-009-00304-2 | 3 | Yageo Group | RC0603FR-072K2L | Arrow Electronics | RC0603FR-072K2L
C23186 | RC0603FR-075K1L | Fixed Resistor, Metal Glaze/thick Film, 0.1W, 5100ohm, 75V, 1% +/-Tol, 100ppm/Cel, Surface Mount, 0603 | R22, R23 | RESC1608X06N_0603_MED | CMP-009-00331-3 | 2 | Yageo Group | RC0603FR-075K1L | DigiKey | 311-5.10KHRDKR-ND
 | RC0603FR-074K7L | Fixed Resistor, Metal Glaze/thick Film, 0.1W, 4700ohm, 75V, 1% +/-Tol, 100ppm/Cel, Surface Mount, 0603 | R24 | RESC1608X06N_0603_MED | CMP-009-00343-1 | 1 | Yageo Group | RC0603FR-074K7L | DigiKey | 311-4.70KHRDKR-ND
C98220 | RC0603FR-1010KL | Fixed Resistor, Metal Glaze/thick Film, 0.1W, 10000ohm, 75V, 1% +/-Tol, 100ppm/Cel, Surface Mount, 0603 | R25, R26, R39, R41 | RESC1608X06N_0603_MED | CMP-009-00306-2 | 4 | Yageo Group | RC0603FR-1010KL | Arrow Electronics | RC0603FR-1010KL
 | RC1206FR-0710KL | Fixed Resistor, Metal Glaze/thick Film, 0.25W, 20000ohm, 200V, 1% +/-Tol, 100ppm/Cel, Surface Mount, 1206 | R36 | RESC3116X06N_1206MED | CMP-009-00344-1 | 1
 | RC0603FR-0718KL | 100mW Thick Film Resistors 75V ±100ppm/℃ ±1% 18kΩ 0603 Chip Resistor - Surface Mount ROHS | R37 | RESC1608X06N_0603_MED | CMP-009-00346-2 | 1
C123417 | RC0603FR-0720KL | 100mW Thick Film Resistors 75V ±100ppm/℃ ±1% 20kΩ 0603 Chip Resistor - Surface Mount ROHS | R40, R42 | RESC1608X06N_0603_MED | CMP-009-00345-1 | 2
 | W6300-EVB-PICO2 | Raspberry Pi RP2350 and fully hardwired TCP/IP controller W6300 | U1 | W6300-EVB-PICO2_0.4375_standoff | CMP-020-00030-3 | 1 | WIZnet | W6300-EVB-PICO2 | Arrow Electronics | W6300-EVB-PICO2
 | FT232RNL | Integrated Circuit Interface USB-UART; RS-232; 12Mbs; 3.3-5.25V; -40+85 deg.C; SMD; SSOP28 | U2 | FP-FT232RNL-REEL-MFG | CMP-015-00034-4 | 1 | FTDI | FT232RL
 | TLP2368(TPL,E | Logic IC Output Optocoupler, 1-Channel, 1-Element, 3750V Isolation, 20MBps | U3, U7, U8 | SOT125P700X220-5N | CMP-00026-00002-1 | 3 | Toshiba | TLP2368(TPL,E | Arrow Electronics | TLP2368(TPL,E
C3235232 | THVD1400DR | Line Transceiver, 1 Func, 1 Driver, 1 Rcvr, PDSO8 | U4 | SOIC127P600X175-8N | CMP-015-00028-2 | 1 | Texas Instruments | THVD1400DR | Texas Instruments | THVD1400DR
C7519 | USBLC6-2SC6 | Very low capacitance ESD protection | U5 | ESD_SOT23-6L | CMP-128-000006-4 | 1 | STMicroelectronics | USBLC6-2SC6 | Newark | USBLC6-2SC6
 | TLV75733PDYDR | 1-A, low-IQ high-accuracy low-dropout (LDO) voltage regulator with enable 5-SOT-23 -40 to 125 | U9 | SOT95P280X145-5N | CMP-019-00080-1 | 1 | Texas Instruments | TLV75733PDYDR | Texas Instruments | TLV75733PDYDR
C6931 | SN74ACT245PWR | Bus Transceiver, ACT Series, 1-Func, 8-Bit, True Output, CMOS, PDSO20 | U10 | PW0020A_L | CMP-016-00027-3 | 1 | Texas Instruments | SN74ACT245PWR | Arrow Electronics | SN74ACT245PWR
 | PCA9633DP1,118 | PCA9633 Series 25 mA 5.5 V 1 MHz SMT 8-bit I2C-Bus LED Driver - TSSOP-8 | U11 | NXP-TSSOP-8_M | CMP-015-00036-1 | 1 | NXP Semiconductors | PCA9633DP1,118 | Newark | PCA9633DP1,118
 | TCA9555PWR | 16-bit 1.65- to 5.5-V I2C/SMBus I/O expander with interrupt, weak pull-up & config registers | U12 | PW0024A_M | CMP-015-00012-2 | 1 | Texas Instruments | TCA9555PWR | Mouser | 595-TCA9555PWR
C83836 | M24C02-RMN6TP | M24C02 Series 2 Kb (256 x 8) 1.8 V SMT Serial I²C Bus EEPROM - SOIC-8 | U13 | M24C02-RMN6TP-SO8N-IPC_B | CMP-019-00078-2 | 1 | STMicroelectronics | M24C02-RMN6TP | Arrow Electronics | M24C02-RMN6TP
 | TPS2553DBVR-1 | IC PWR SWITCH N-CHAN 1: 1 SOT23-6 Power Switch/Driver 1: 1 N-Channel 1.5A SOT-23-6 | U14 | DBV0006A_N | CMP-019-00083-1 | 1

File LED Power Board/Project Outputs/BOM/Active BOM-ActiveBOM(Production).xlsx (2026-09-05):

JLCPN | Name | Description | Designator | Footprint | LibRef | Quantity | Manufacturer 1 | Manufacturer Part Number 1 | Supplier 1 | Supplier Part Number 1
 | REH1020471M050K | CAP ALUM 470UF 20% 50V RADIAL TH | C1, C2, C3, C4, C5, C6, C7, C8 | CAP_POL_DIAM10_H22_SPACING5 | CMP-001-00166-2 | 8 | KYOCERA AVX | REH1020471M050K | Mouser | 581-REH1020471M050K
 | 5.0SMDJ5.0A | 5V Unidirectional 5kW TVS Diode, 9.2V Vwm, 6.4V Vbr, SMC(DO-214AB), SMD | D1 | SMDJ_DO-214AB | CMP-004-00056-1 | 1
 | 3544-2 | Auto blade fuse holder; for 2.8x0.8mm mini blade fuses ATM; 20A; THT | F1, F2, F5, F6, F10, F11, F15, F16 | 3544-2-Footprint-1 | CMP-005-00025-1 | 8 | Keystone | 3544-2 | Heilind Americas | 3544-2
 | 0297005.WXNV | Fuse Blade 5A 32V Socket 10.9 X 3.8 X 8.8mm Polyamide 66 Automotive UL | F3, F4, F7, F8, F9, F12, F13, F14 | FP-0297-MFG | CMP-005-00024-3 | 8 | Littelfuse | 0297005.WXNV | Arrow Electronics | 0297005.WXNV
 | 691351500002 | Terminal Block, Pluggable, 2Pos, 12Awg; | J1, J2, J4, J5, J7, J8, J9, J10 | 691351500002-Footprint-1 | CMP-002-00248-4 | 8 | Wurth Elektronik | 691351500002 | DigiKey | 732-2040-ND
 | OSTYK51102030 | Conn Terminal Block 2 POS 9.5mm Solder ST Thru-Hole 30A | J3, J6 | OSTYK51102030-Footprint-1 | CMP-002-00246-1 | 2 | On Shore Technology | OSTYK51102030 | DigiKey | ED2953-ND
 | 691319510004 | Terminal Block, 5.08MM, Dbl Lvl Horizontal Male Pcb Header W/closed Flange, 4PI | P1, P2, P3, P4 | 691319510004 | CMP-002-00244-2 | 4 | Wurth Elektronik | 691319510004
 | RC1206FR-0710KL | Fixed Resistor, Metal Glaze/thick Film, 0.25W, 20000ohm, 200V, 1% +/-Tol, 100ppm/Cel, Surface Mount, 1206 | R1 | RESC3116X06N_1206MED | CMP-009-00344-1 | 1 | Yageo Group | RC1206FR-0710KL | Mouser | 603-RC1206FR-0710KL

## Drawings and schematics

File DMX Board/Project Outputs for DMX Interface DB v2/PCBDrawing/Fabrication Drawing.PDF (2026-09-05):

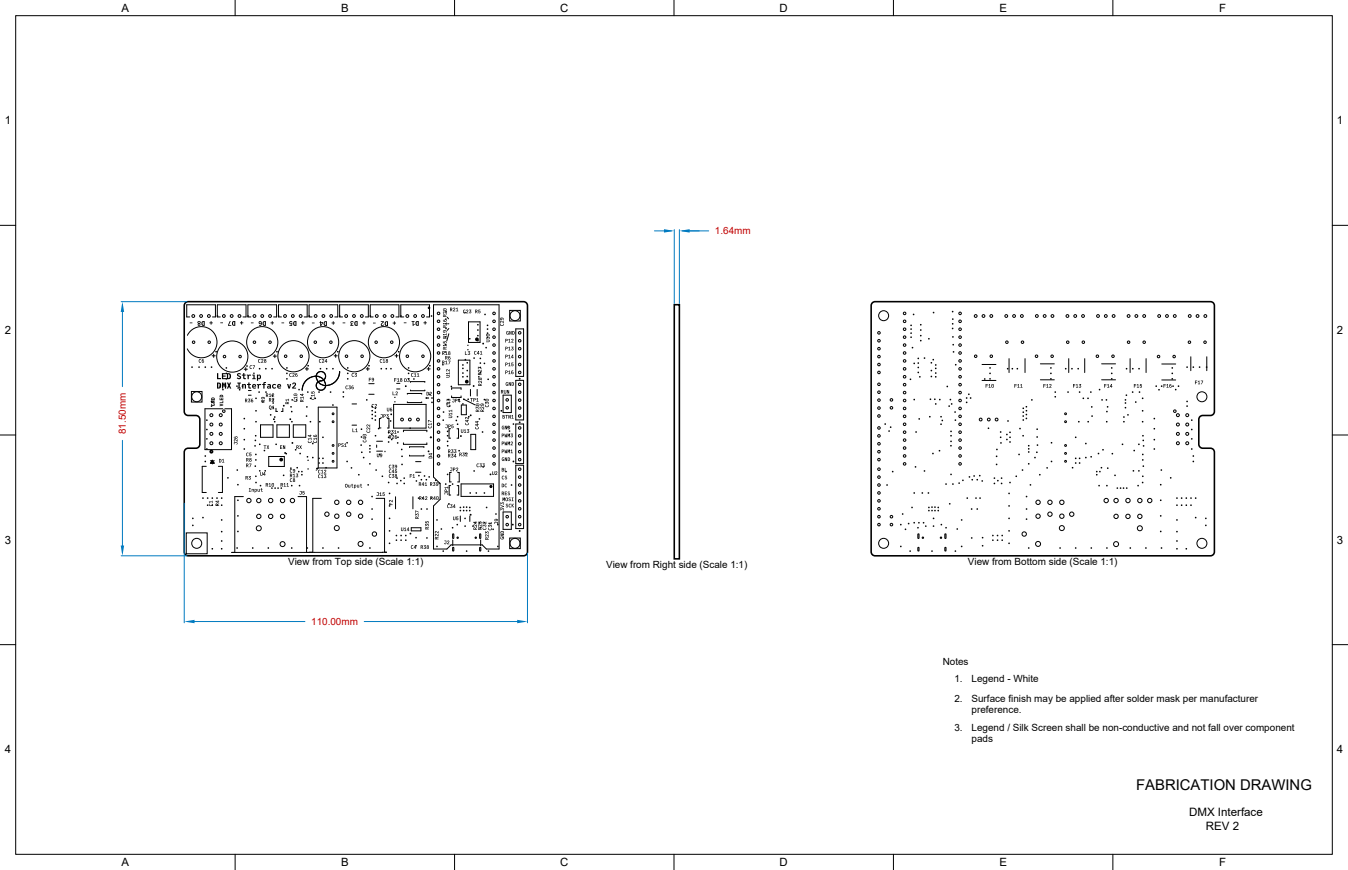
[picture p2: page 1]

Notes
1. Legend - White
Surface finish may be applied after solder mask per manufacturer
preference.
Legend / Silk Screen shall be non-conductive and not fall over component
pads

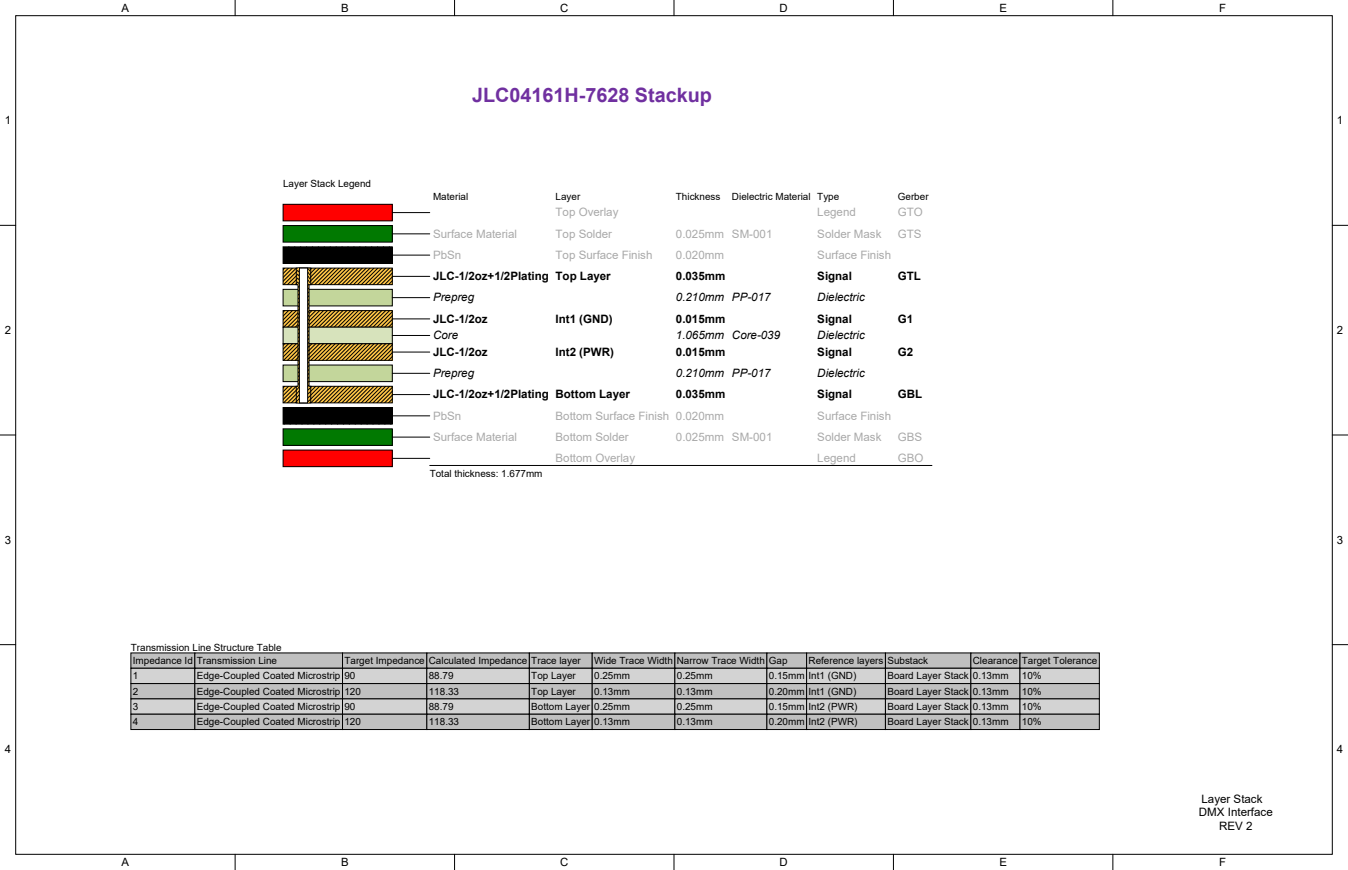
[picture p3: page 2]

Transmission Line Structure Table

Impedance Id | Transmission Line | Target Impedance | Calculated Impedance | Trace layer | Wide Trace Width | Narrow Trace Width | Gap | Reference layers | Substack | Clearance | Target Tolerance
1 | Edge-Coupled Coated Microstrip | 90 | 88.79 | Top Layer | 0.25mm | 0.25mm | 0.15mm | Int1 (GND) | Board Layer Stack | 0.13mm | 10%
2 | Edge-Coupled Coated Microstrip | 120 | 118.33 | Top Layer | 0.13mm | 0.13mm | 0.20mm | Int1 (GND) | Board Layer Stack | 0.13mm | 10%
3 | Edge-Coupled Coated Microstrip | 90 | 88.79 | Bottom Layer | 0.25mm | 0.25mm | 0.15mm | Int2 (PWR) | Board Layer Stack | 0.13mm | 10%
4 | Edge-Coupled Coated Microstrip | 120 | 118.33 | Bottom Layer | 0.13mm | 0.13mm | 0.20mm | Int2 (PWR) | Board Layer Stack | 0.13mm | 10%

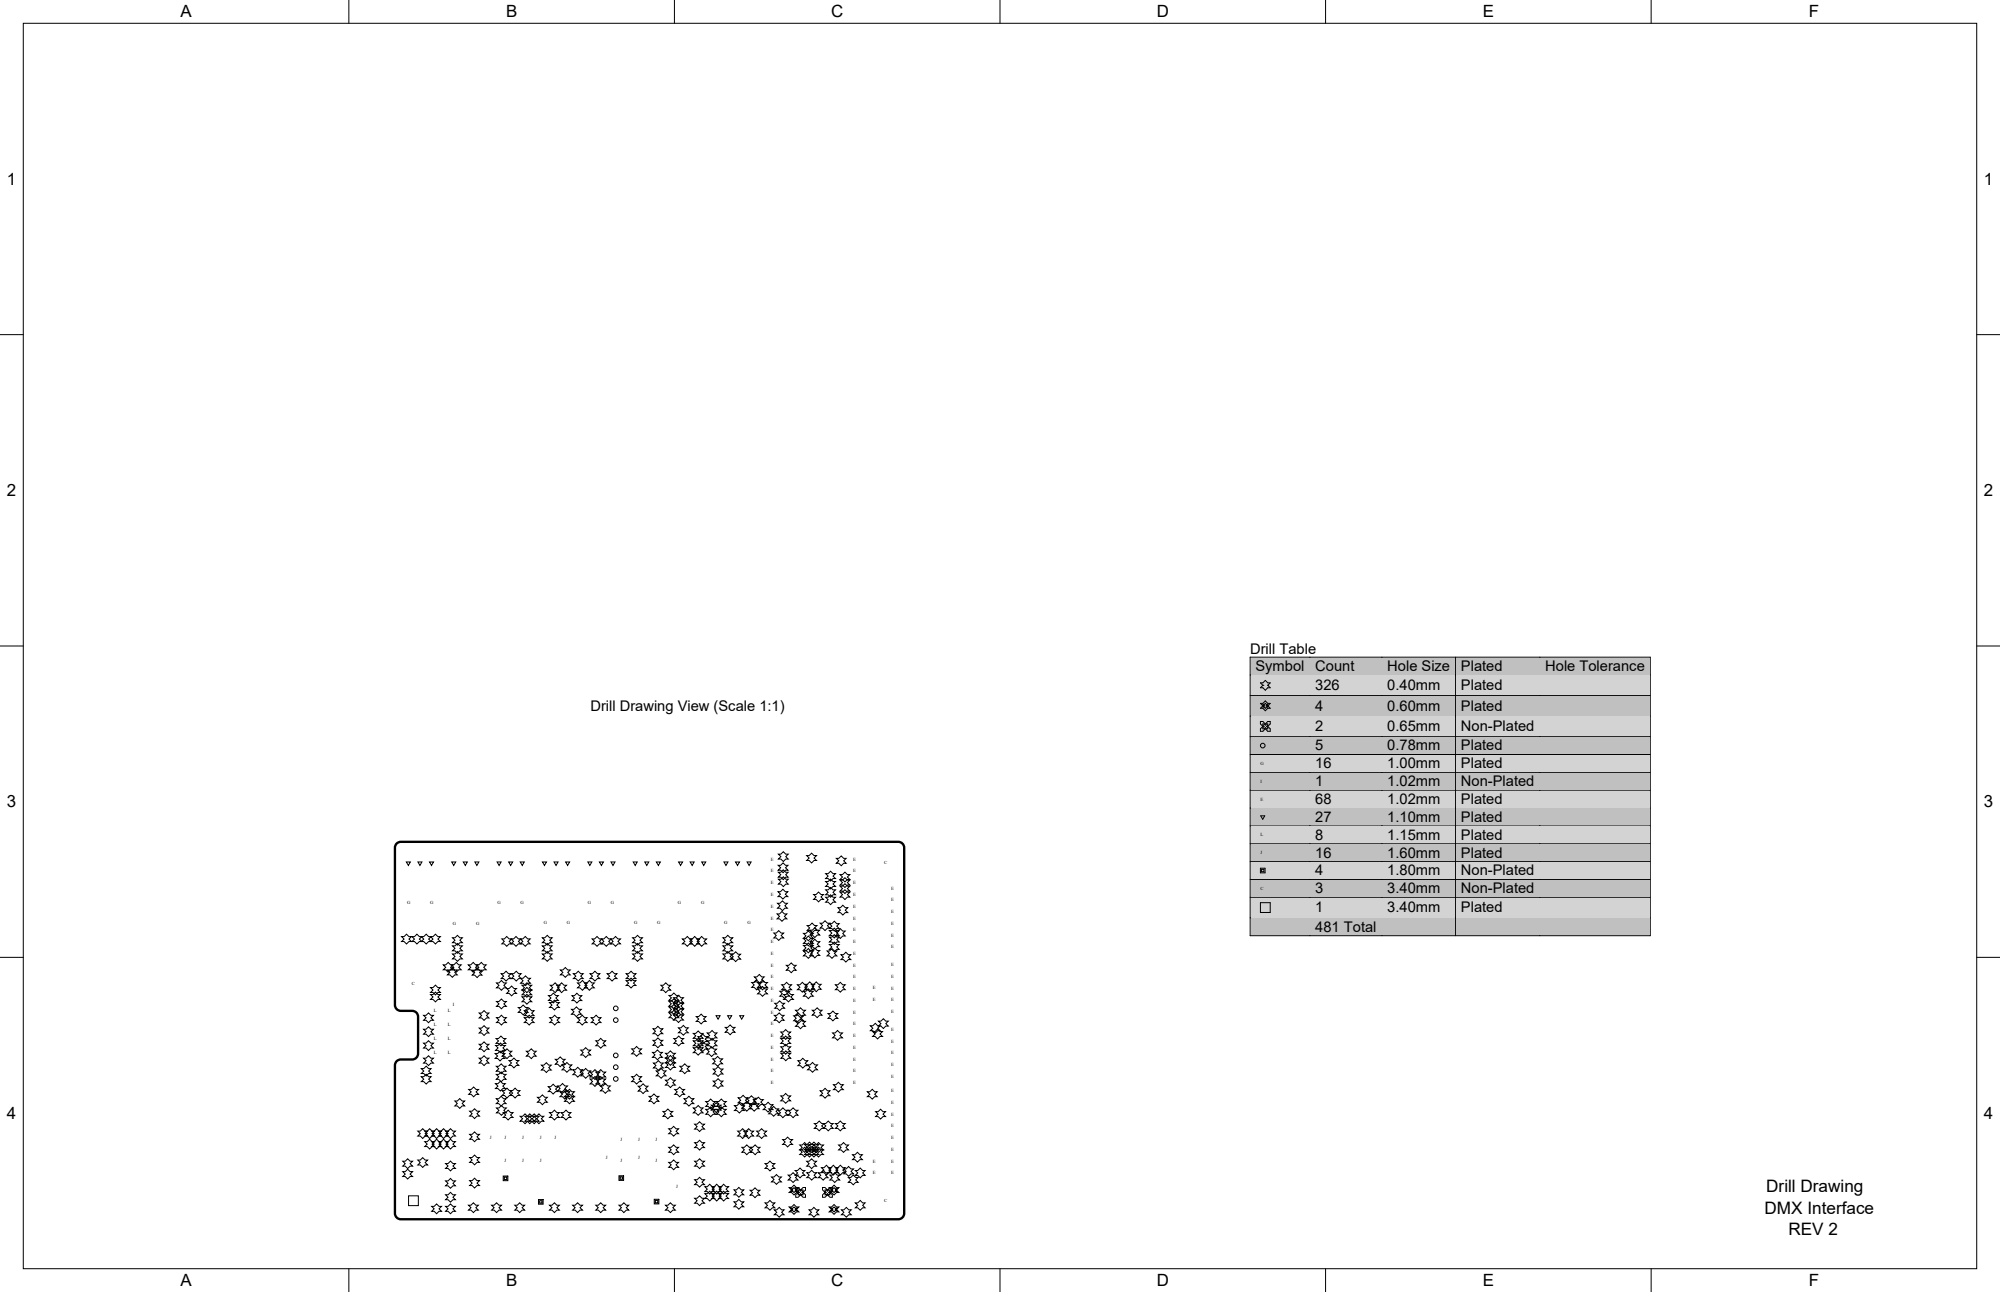
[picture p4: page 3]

Symbol | Count | Hole Size | Plated | Hole Tolerance

326 | 0.40mm | Plated
4 | 0.60mm | Plated
2 | 0.65mm | Non-Plated
5 | 0.78mm | Plated

Drill Drawing View (Scale 1:1)

G | 16 | 1.00mm | Plated

I | 1 | 1.02mm | Non-Plated

E | 68 | 1.02mm | Plated

27 | 1.10mm | Plated

L | 8 | 1.15mm | Plated

J | 16 | 1.60mm | Plated

4 | 1.80mm | Non-Plated

C | 3 | 3.40mm | Non-Plated

1 | 3.40mm | Plated
481 Total

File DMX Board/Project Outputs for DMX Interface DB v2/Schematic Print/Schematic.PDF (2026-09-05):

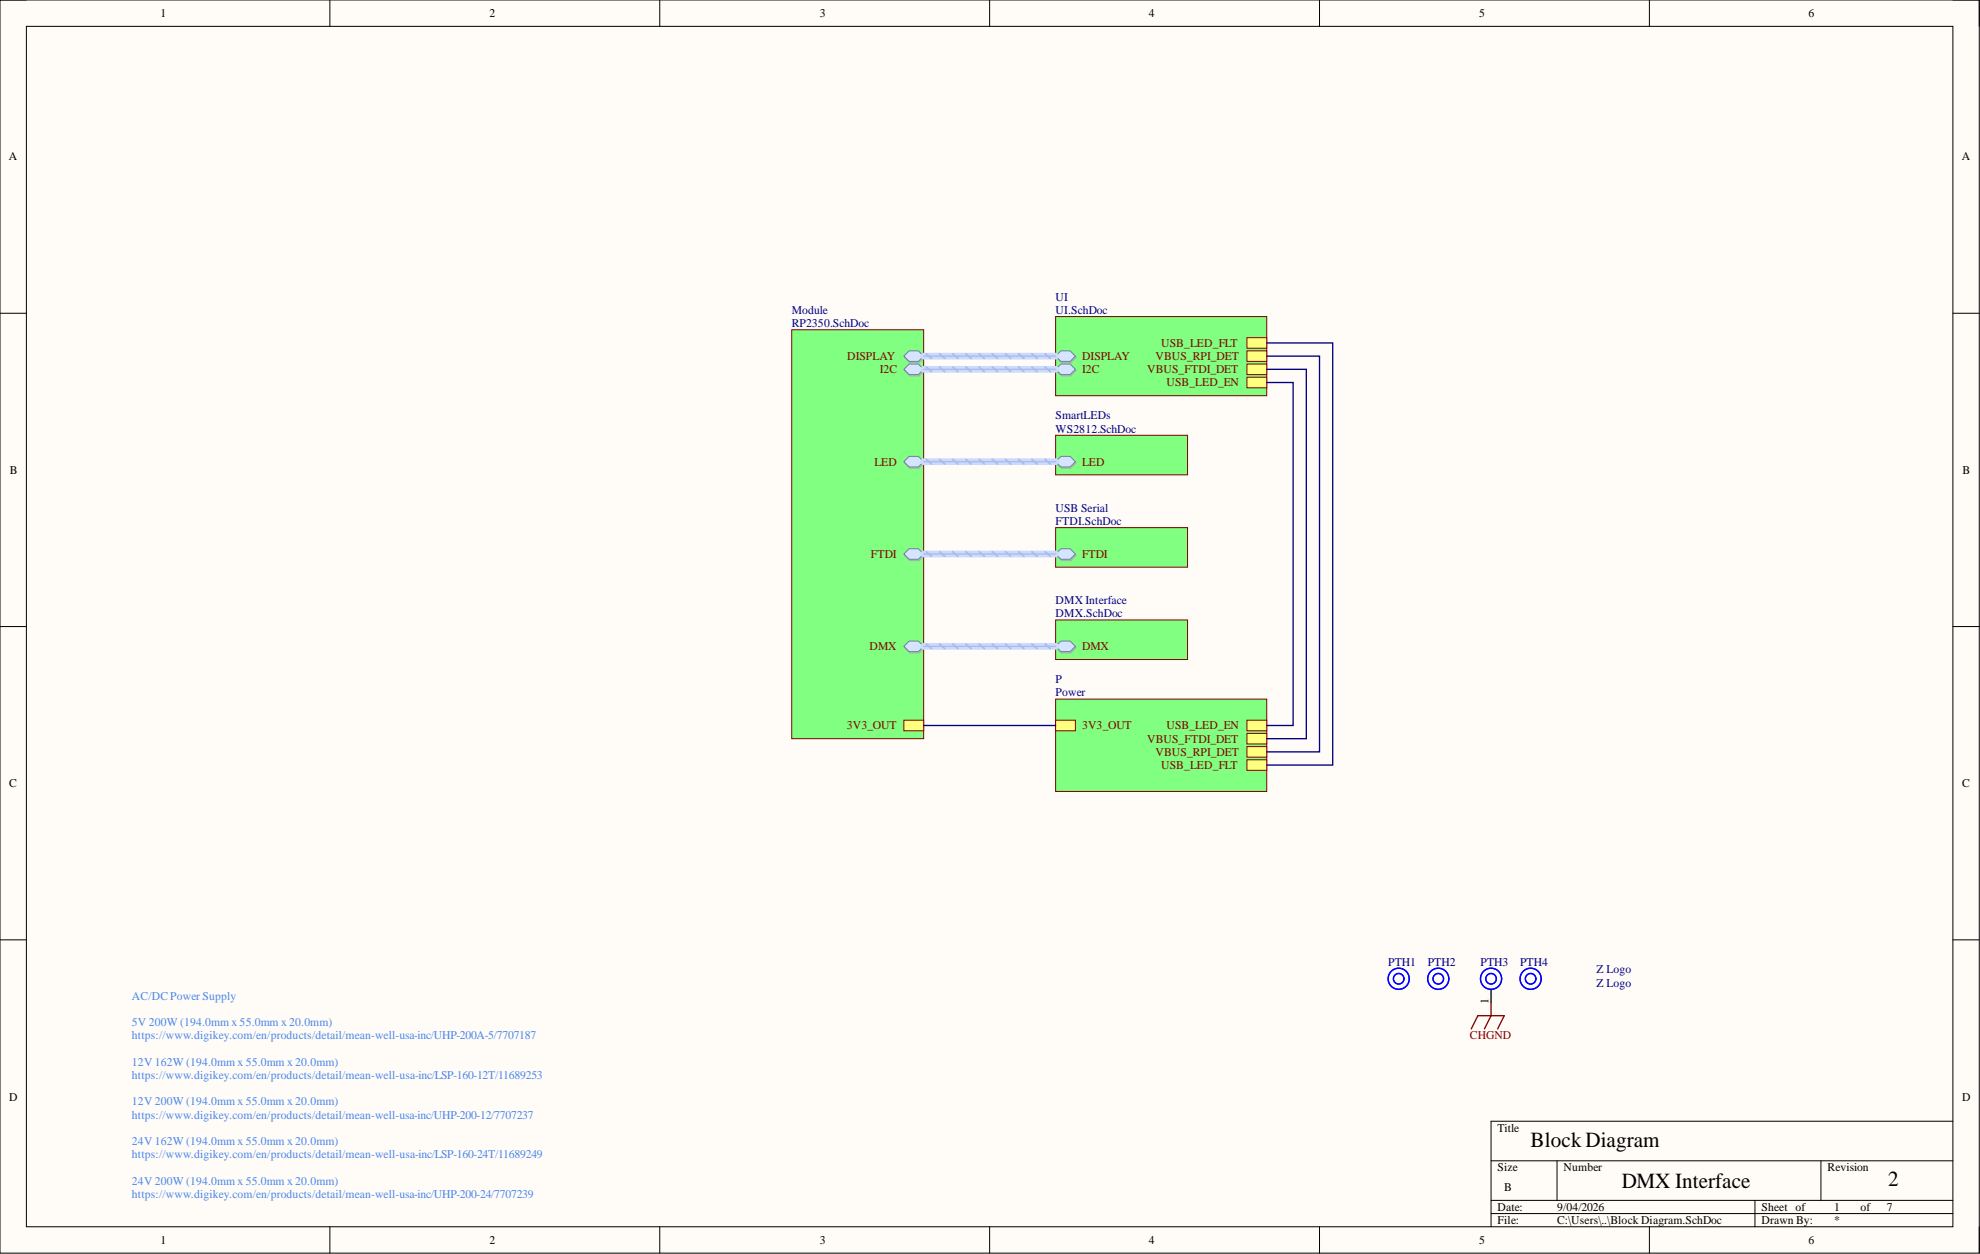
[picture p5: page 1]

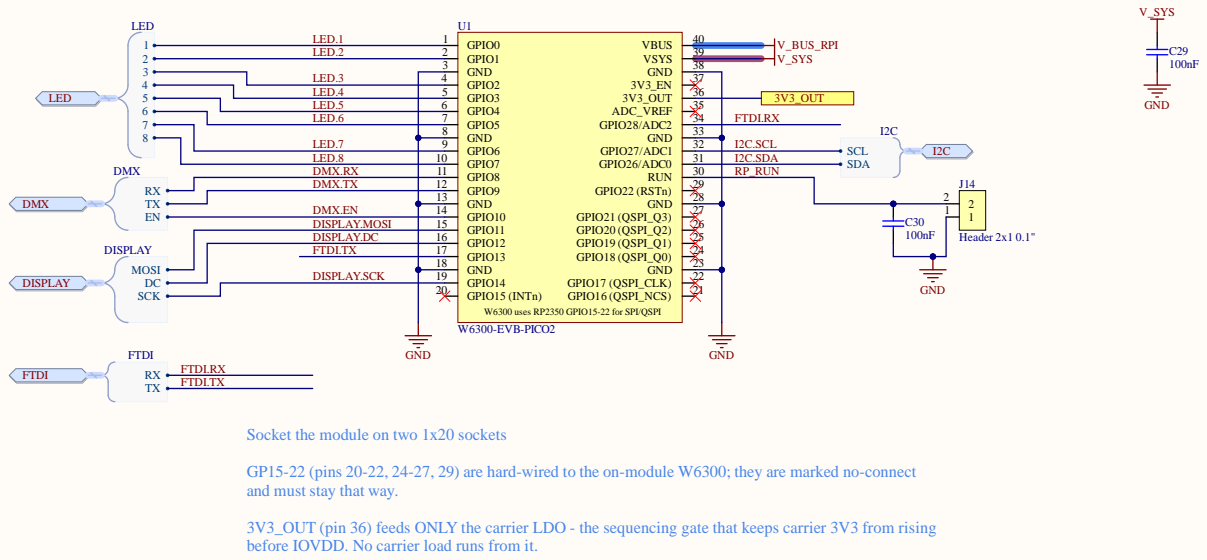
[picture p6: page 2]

L E D . 3 | | 4 | 3 7 6
L E D . 4 | | 5 | 3
L E D . 5 | | 6 | 3 5 4 3
L E D . 6 | | 7 | 3 3

L E D . 7 | | 9 | 3 2 3 1 30 9 RUN
L E D . 8 | 1 | 0

1 4 | | | 2 7 6 5 4 3 | 1
1 5 | | | 2

DISPL AY. D C | 1 | 6 | | 2
FT DI. T X | 1 1 | 7 8 | | 2

DISPL AY.S C K | 1 | 9 | 2 2 1

that keeps carrier 3V3 from rising

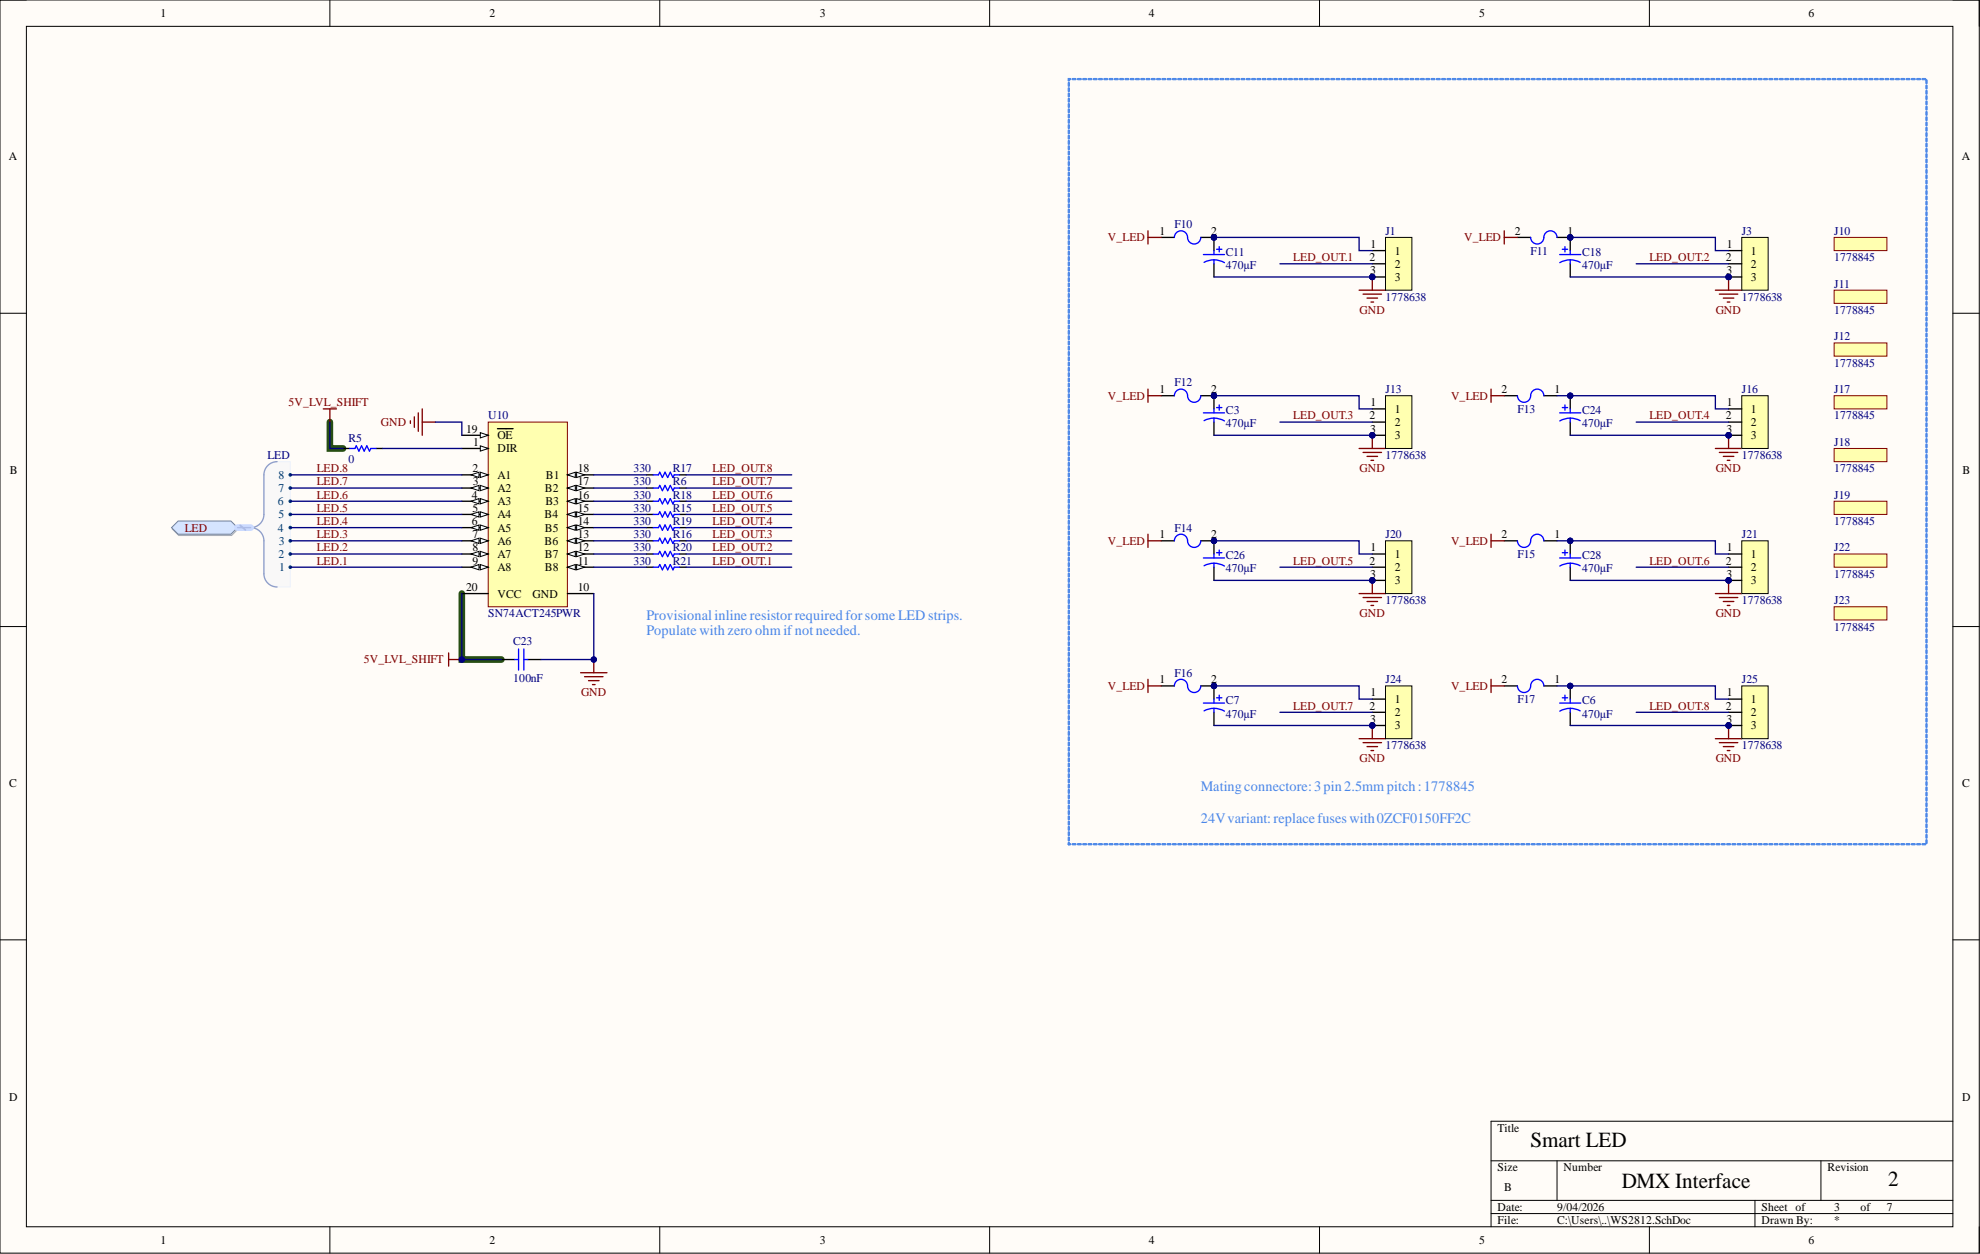
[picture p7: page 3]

d for some LED strips.

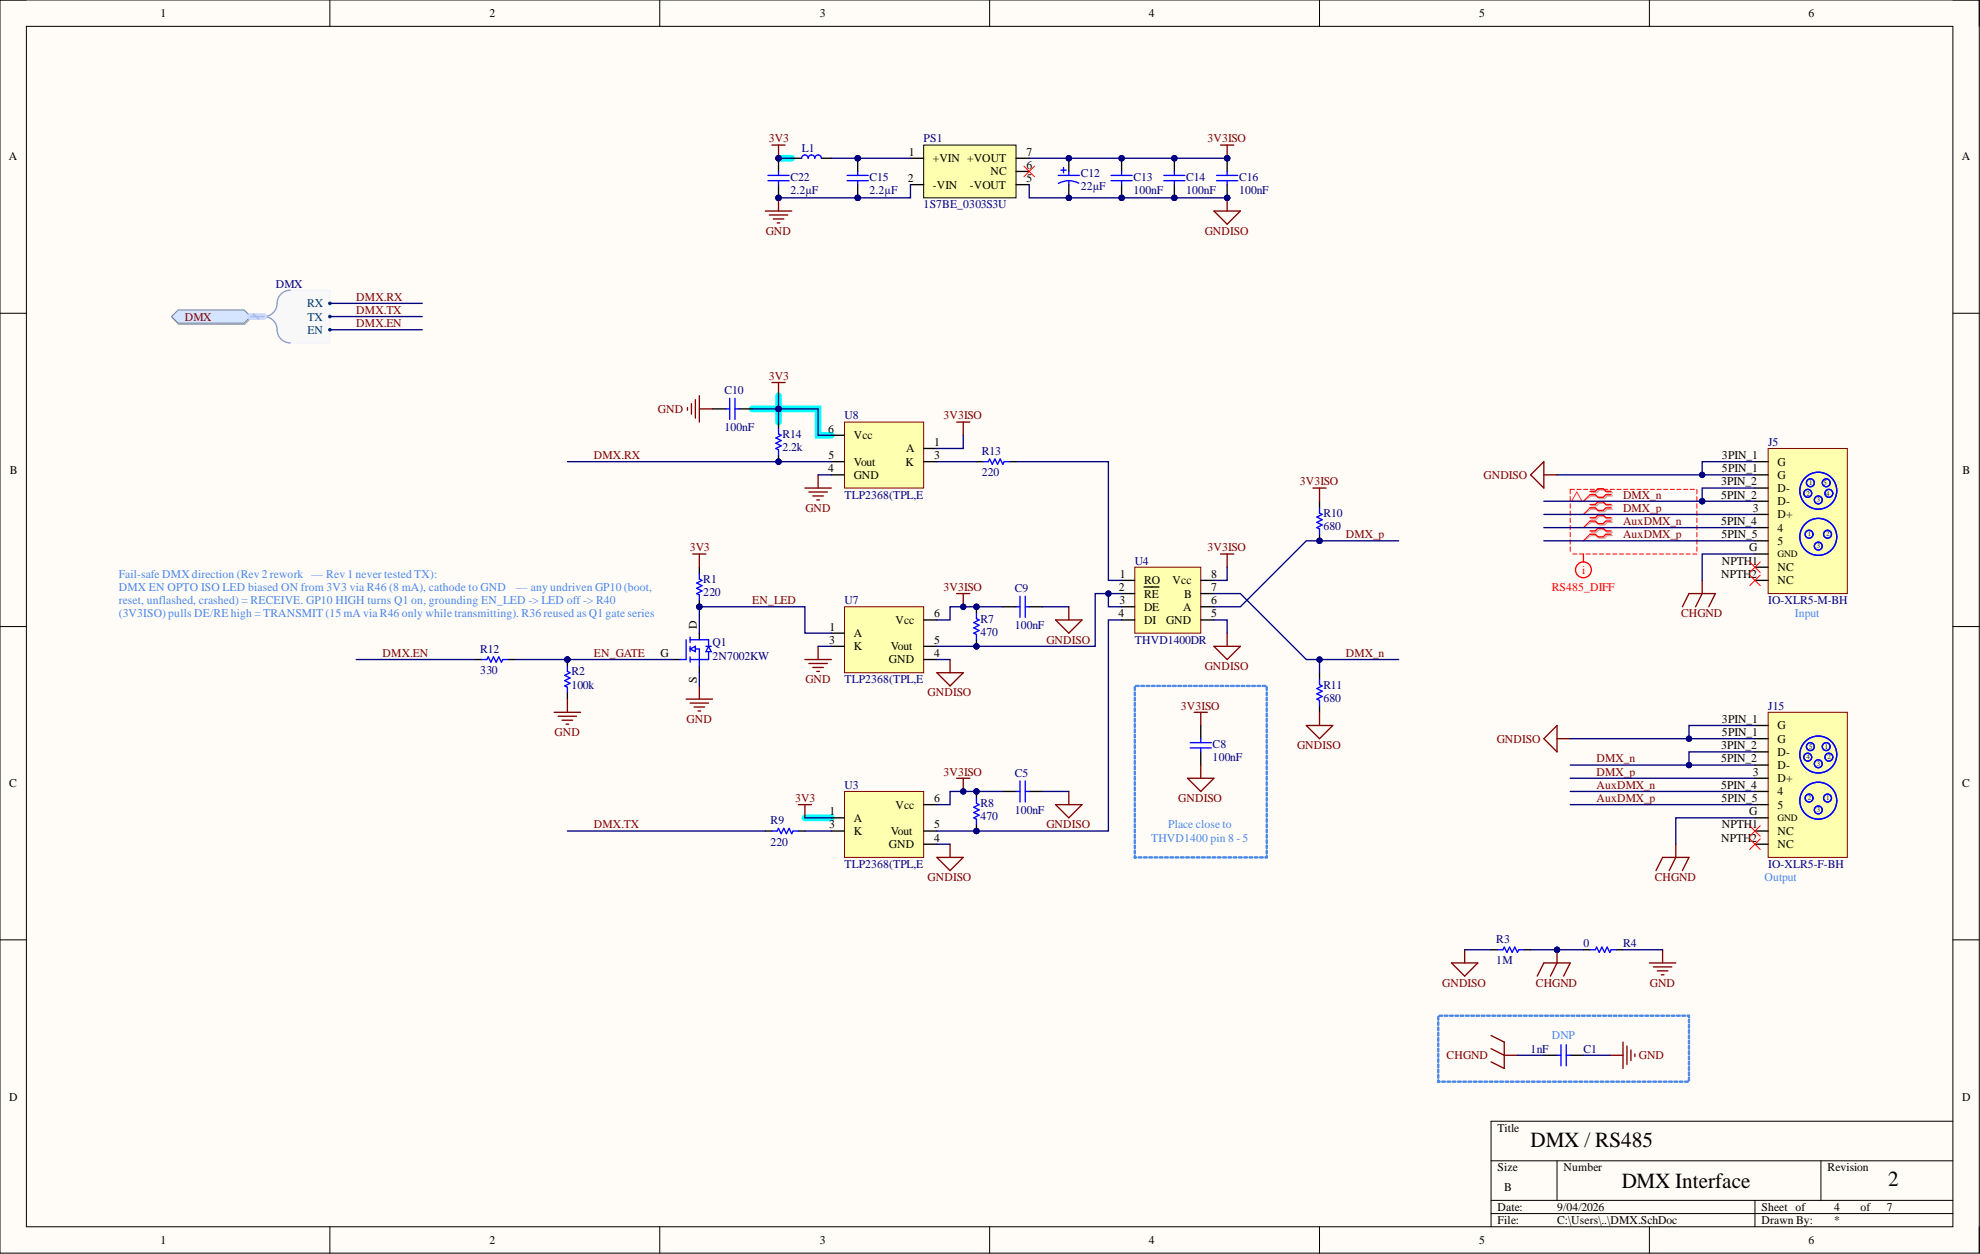
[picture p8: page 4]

DMX_p | D+ 3
AuxDMX_n | 4 5PIN_4
AuxDMX_p | 5 5PIN_5

GND G
NC NPTH1

Fail-safe DMX direction (Rev 2 rework — Rev 1 never tested TX):
DMX EN OPTO ISO LED biased ON from 3V3 via R46 (8 mA), cathode to GND — any undriven GP10 (boot,
reset, unflashed, crashed) = RECEIVE. GP10 HIGH turns Q1 on, grounding EN_LED -> LED off -> R40
(3V3ISO) pulls DE/RE high = TRANSMIT (15 mA via R46 only while transmitting). R36 reused as Q1 gate series

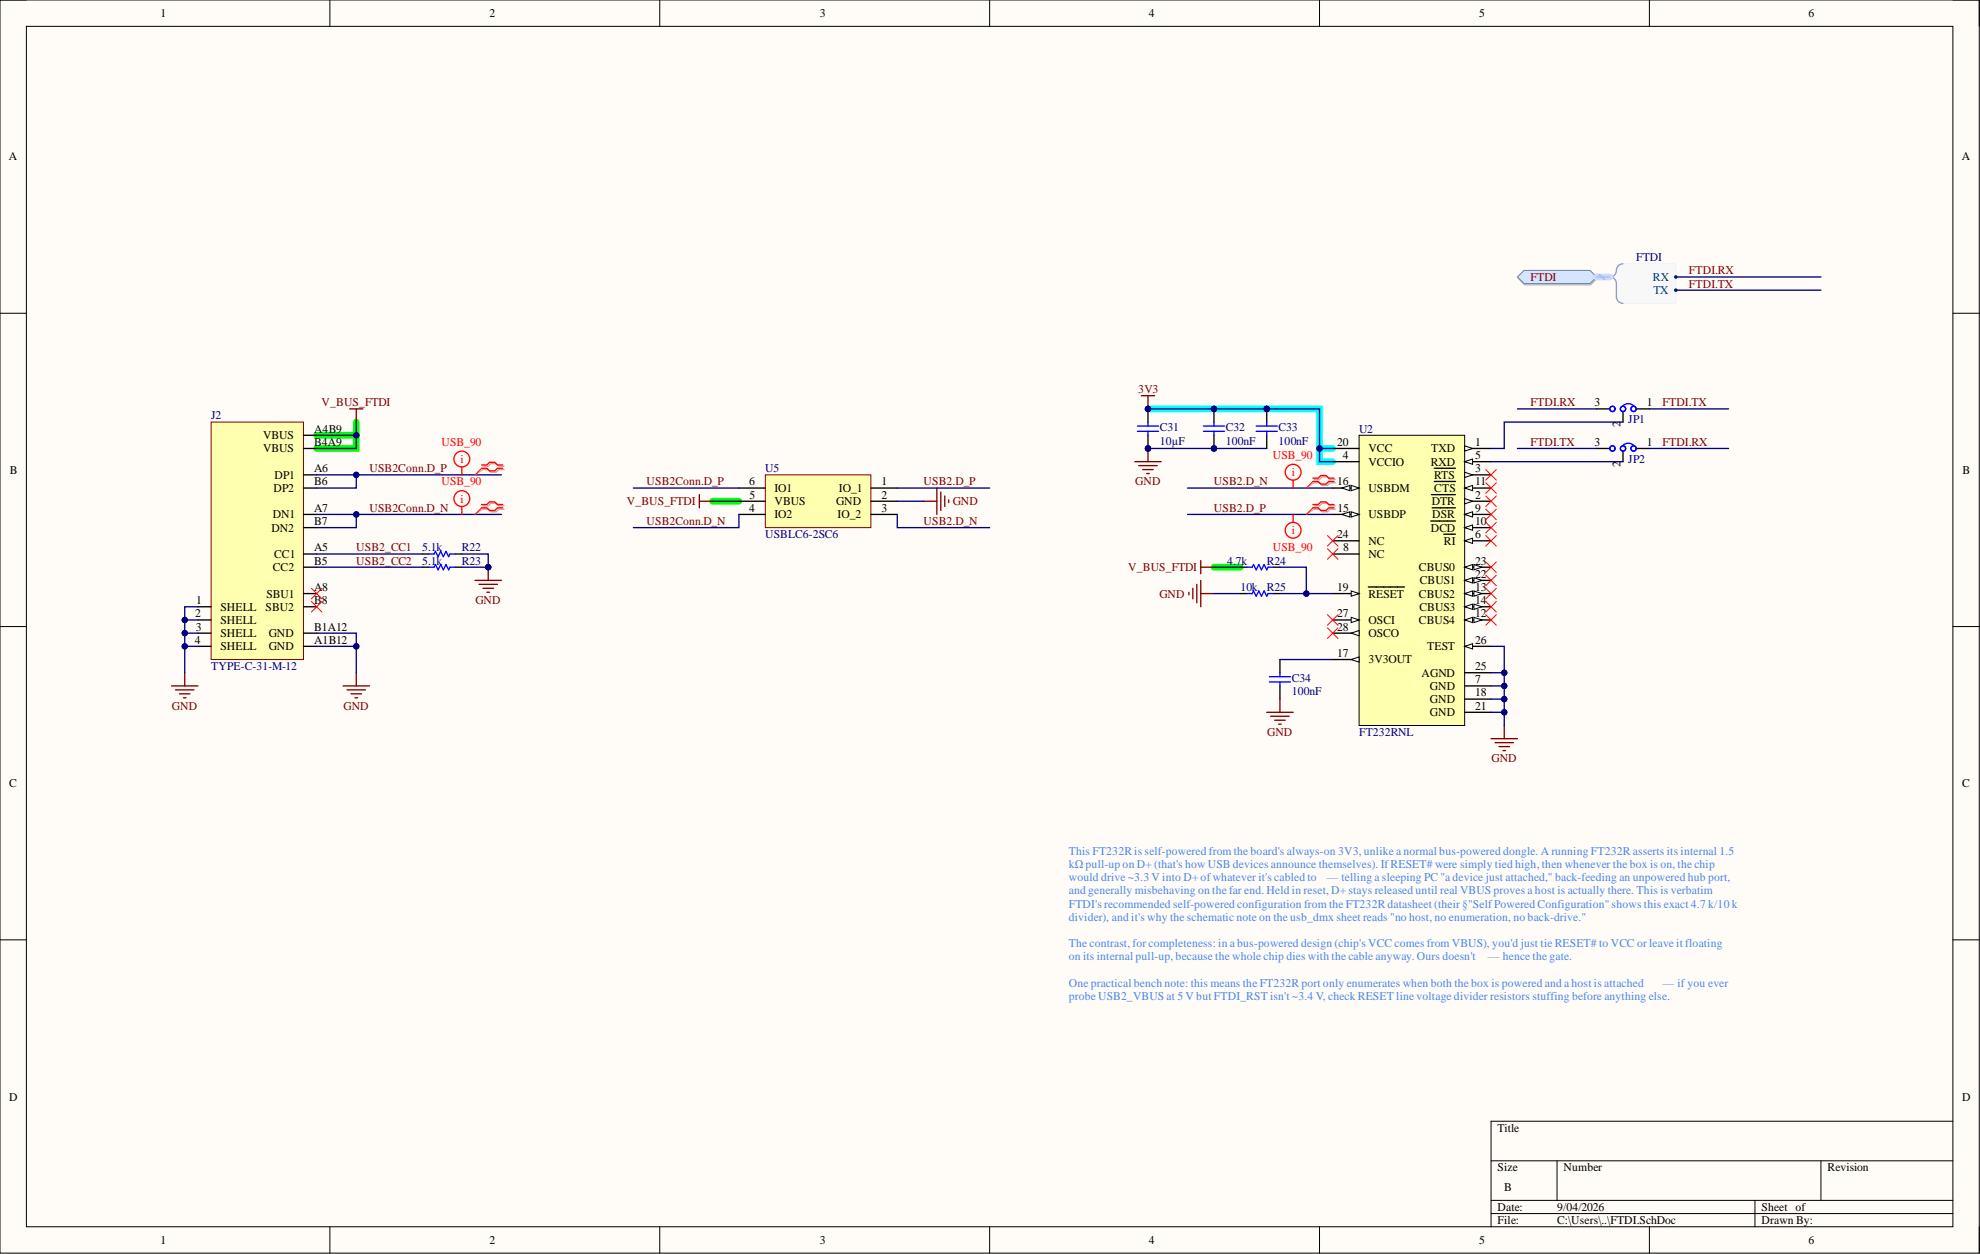
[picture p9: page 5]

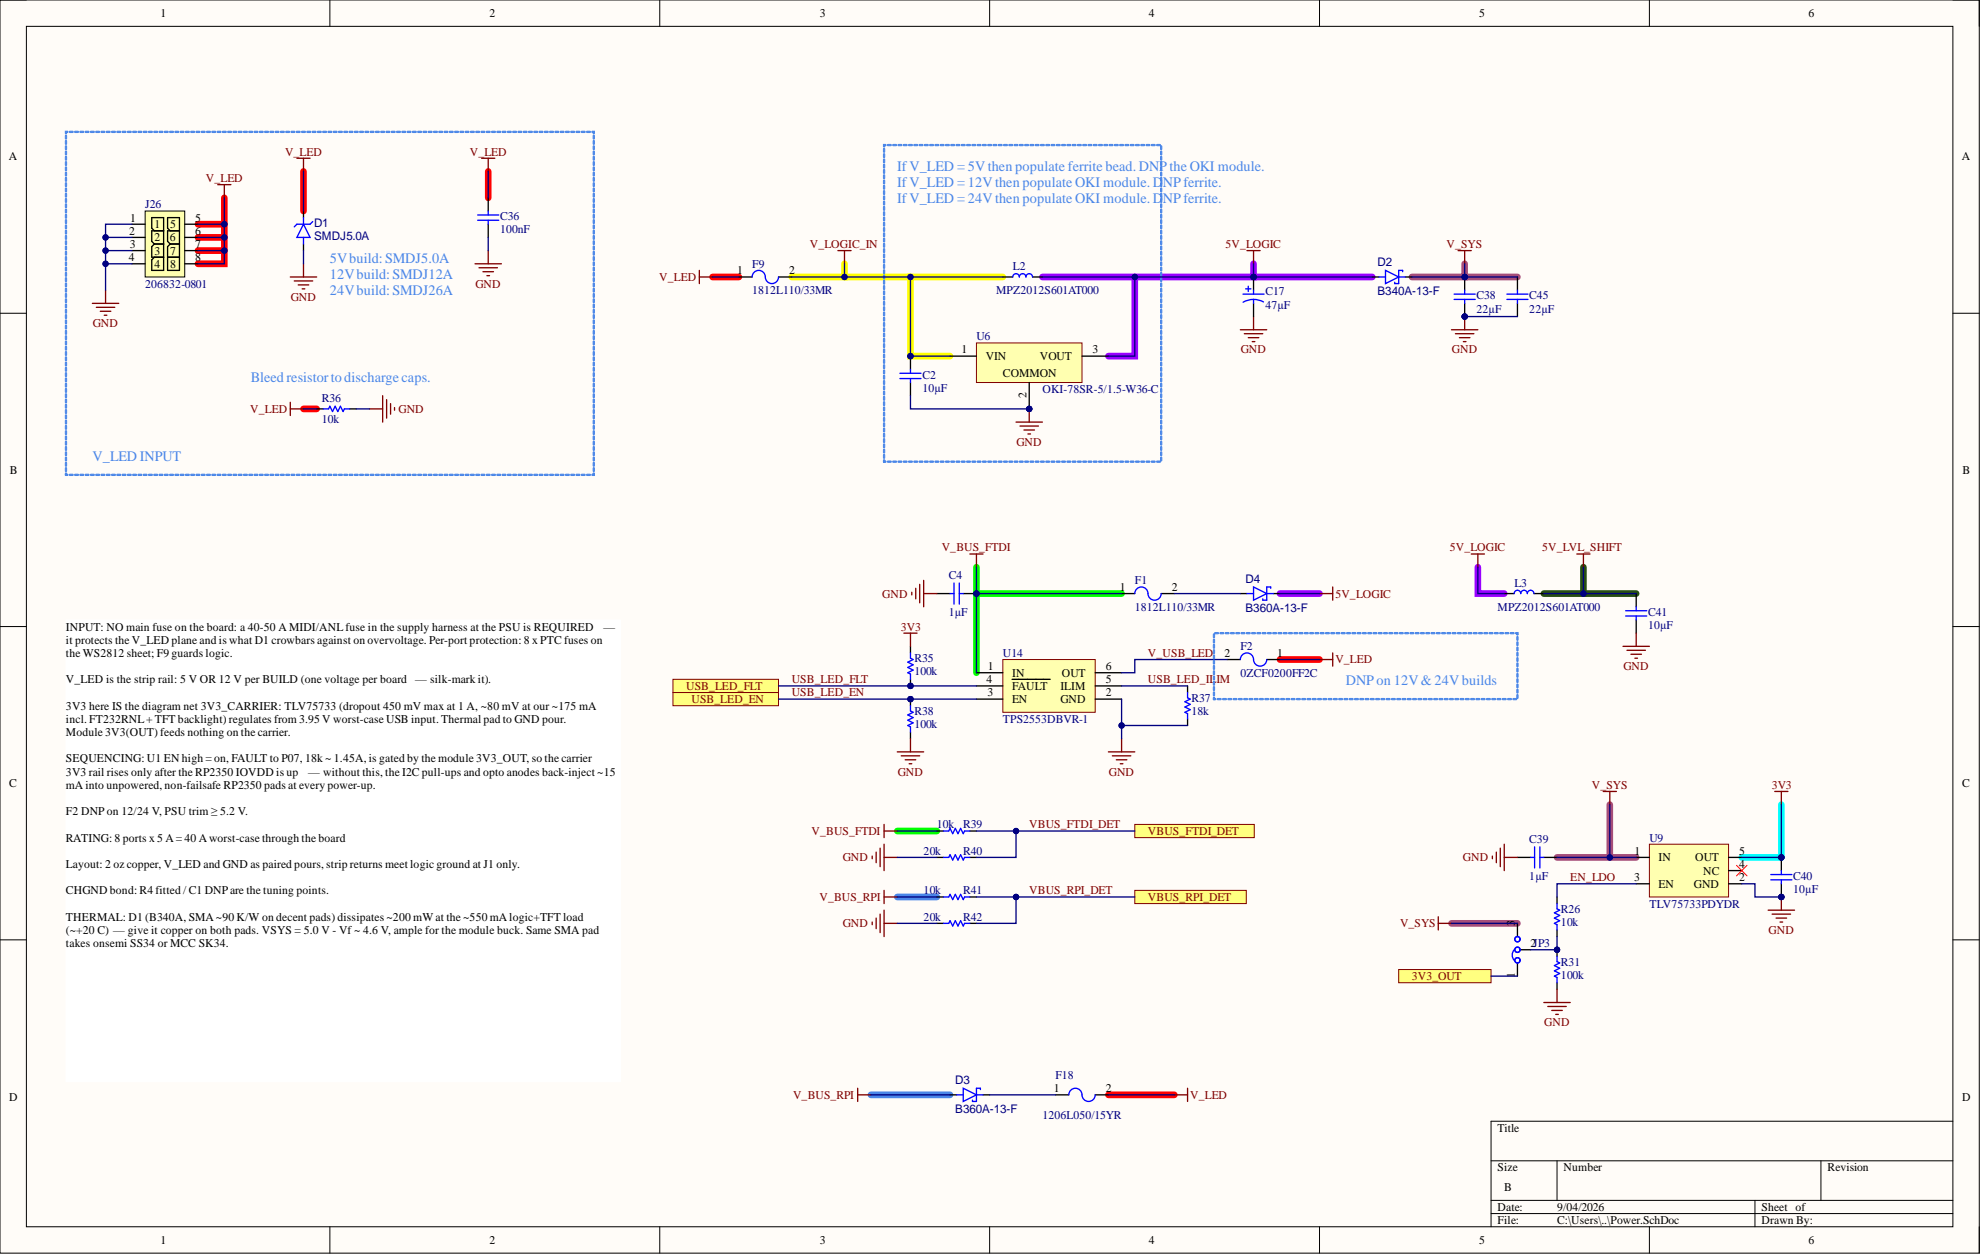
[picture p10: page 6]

If V_LED = 5V then populate ferrite bead. DNP the OKI module.
If V_LED = 12V then populate OKI module. DNP ferrite.
If V_LED = 24V then populate OKI module. DNP ferrite.

Bleed resistor to discharge caps.

INPUT: NO main fuse on the board: a 40-50 A MIDI/ANL fuse in the supply harness at the PSU is REQUIRED —
it protects the V_LED plane and is what D1 crowbars against on overvoltage. Per-port protection: 8 x PTC fuses on
the WS2812 sheet; F9 guards logic.

V_LED is the strip rail: 5 V OR 12 V per BUILD (one voltage per board — silk-mark it).

3V3 here IS the diagram net 3V3_CARRIER: TLV75733 (dropout 450 mV max at 1 A, ~80 mV at our ~175 mA
incl. FT232RNL+ TFT backlight) regulates from 3.95 V worst-case USB input. Thermal pad to GND pour.
Module 3V3(OUT) feeds nothing on the carrier.

SEQUENCING: U1 EN high = on, FAULT to P07, 18k ~ 1.45A, is gated by the module 3V3_OUT, so the carrier
3V3 rail rises only after the RP2350 IOVDD is up — without this, the I2C pull-ups and opto anodes back-inject ~15
mA into unpowered, non-failsafe RP2350 pads at every power-up.

F2 DNP on 12/24 V, PSU trim ≥ 5.2 V.

RATING: 8 ports x 5 A = 40 A worst-case through the board

Layout: 2 oz copper, V_LED and GND as paired pours, strip returns meet logic ground atJ1 only.

CHGND bond: R4 fitted / C1 DNP are the tuning points.

THERMAL: D1 (B340A, SMA ~90 K/W on decent pads) dissipates ~200 mW at the ~550 mA logic+TFT load
(~+20 C) — give it copper on both pads. VSYS = 5.0 V - Vf ~ 4.6 V, ample for the module buck. Same SMA pad
takes onsemi SS34 or MCC SK34.

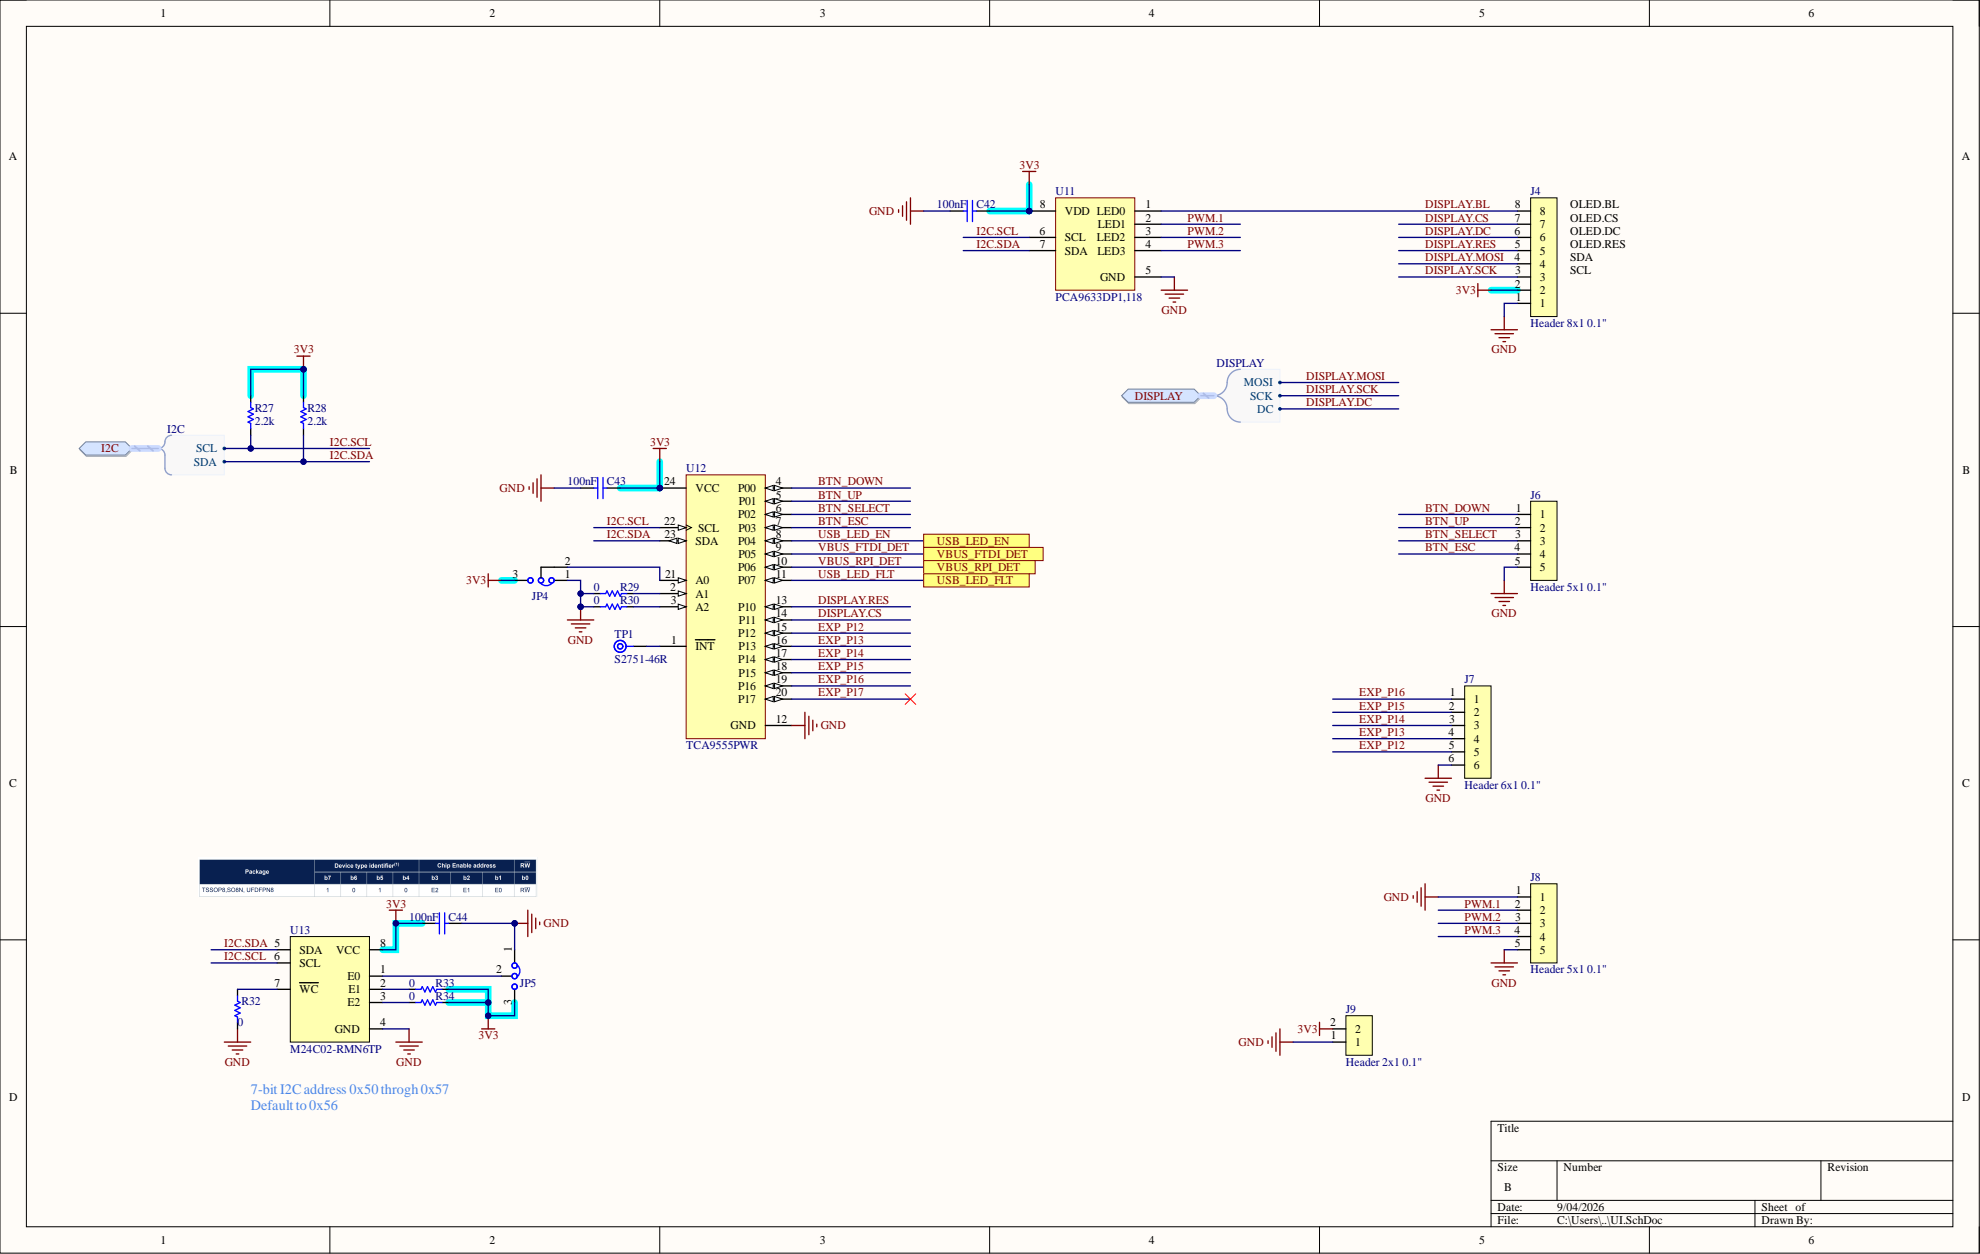
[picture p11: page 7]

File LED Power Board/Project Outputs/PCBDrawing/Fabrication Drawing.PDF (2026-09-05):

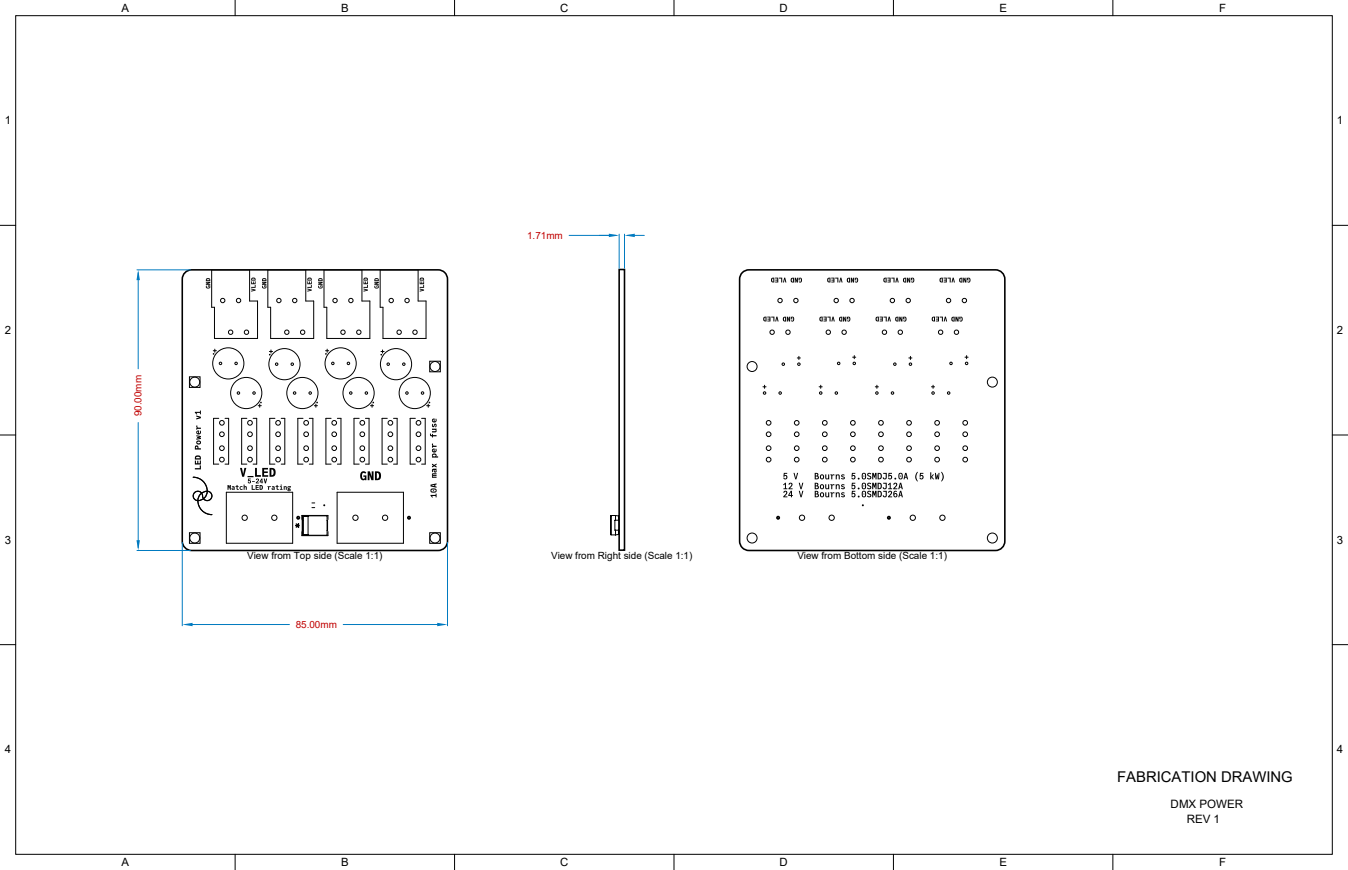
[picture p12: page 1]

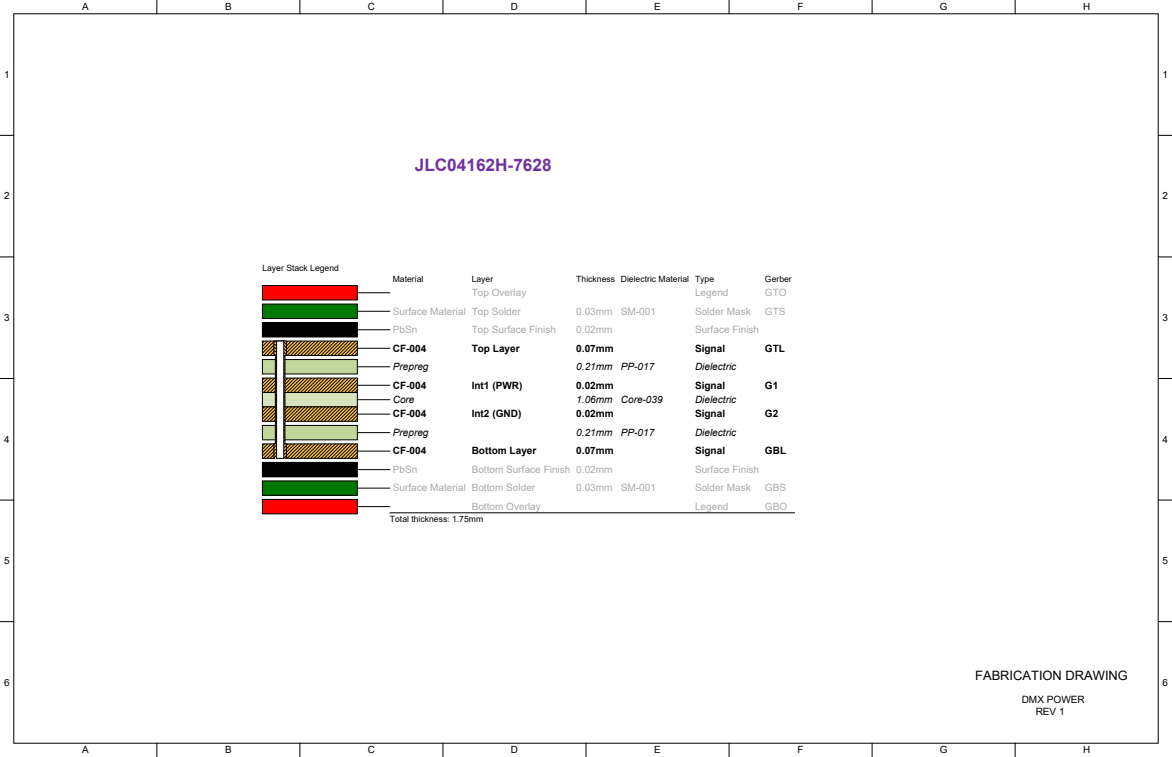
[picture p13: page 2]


Symbol | Count | Hole Size | Plated | Hole Tolerance

1 | 0.51mm | Plated
16 | 1.00mm | Plated
16 | 1.60mm | Plated
32 | 1.70mm | Plated
4 | 1.91mm | Plated
4 | 3.40mm | Non-Plated
73 Total

Drill Drawing View (Scale 1:1)

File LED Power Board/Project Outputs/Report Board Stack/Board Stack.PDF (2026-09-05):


Stack Up | Layer Stack
Layer | Board Layer Stack | Name | Material | Thickness | Constant
1 | | Top Overlay | | 0mil
2 | | Top Solder | SM-001 | 1mil | 4
3 | | Top Surface Finish | PbSn | 0.787mil
4 | | Top Layer | CF-004 | 2.756mil
5 | | Dielectric 1 | PP-017 | 8.284mil | 4.3
6 | | Int1 (PWR) | CF-004 | 0.689mil
7 | | Dielectric 3 | Core-039 | 41.929mil | 4.8
8 | | Int2 (GND) | CF-004 | 0.689mil
9 | | Dielectric 5 | PP-017 | 8.284mil | 4.3
10 | | Bottom Layer | CF-004 | 2.756mil
11 | | Bottom Surface Finish | PbSn | 0.787mil
12 | | Bottom Solder | SM-001 | 1mil | 4
13 | | Bottom Overlay | | 0mil

Height : 68.961mil



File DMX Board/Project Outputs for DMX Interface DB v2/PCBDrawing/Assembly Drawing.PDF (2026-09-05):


Top side component view (Scale 1:1)


Component Detail Top side (Scale 1:1)





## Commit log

2025-09-05 purchase pcb
    [Active BOM-DMX Interface(Production).xlsx, Block Diagram.SchDoc, DMX Interface DB.PrjPcb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]
2026-07-19 add design review
    [Block Diagram.SchDoc, DMX Interface DB.PrjPcb, STM32.SchDoc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]
